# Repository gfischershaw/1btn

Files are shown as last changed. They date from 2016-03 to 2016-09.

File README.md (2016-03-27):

# [1btn](http://www.1btn.space)

1btn (one button) uses the internet to complete a task with the simple, satisfying click of a single button. It connects to the internet over Wi-Fi to trigger whatever action you have assigned to it using a simple, online interface. One click, one task. It’s that simple.

Unlike many other “Internet of Things” devices, 1btn does not maintain a continuous connection to the internet. Instead, it sleeps until it is pressed, then it connects to the internet, performs the assigned task, tells you the outcome via its multi-colored LEDs, and then returns to rest.

As the Internet of Things has expanded, we’ve noticed an unfortunate trend: the increasing use of smartphones to control IoT applications. We don’t think a smartphone provides the best or simplest UI for this purpose. Think of all the steps you need to take to send a single instruction with a smartphone: find the phone, wake it up or power it up, enter your passcode, keep swiping until you find and start up your smart app, select the appropriate control, activate it, and then put the phone back to sleep.

We think there’s a better way, a tried-and-true, more intuitive way, to activate a single task or function, and that’s with a button. Why are buttons such a great idea? A button is the simplest user interface for a single-repetitive-programmable task. They are simple exactly because they are designed for a single-task. More importantly, buttons are easy-to-understand, they are familiar, intuitive, and provide immediate, satisfying physical feedback when pushed.

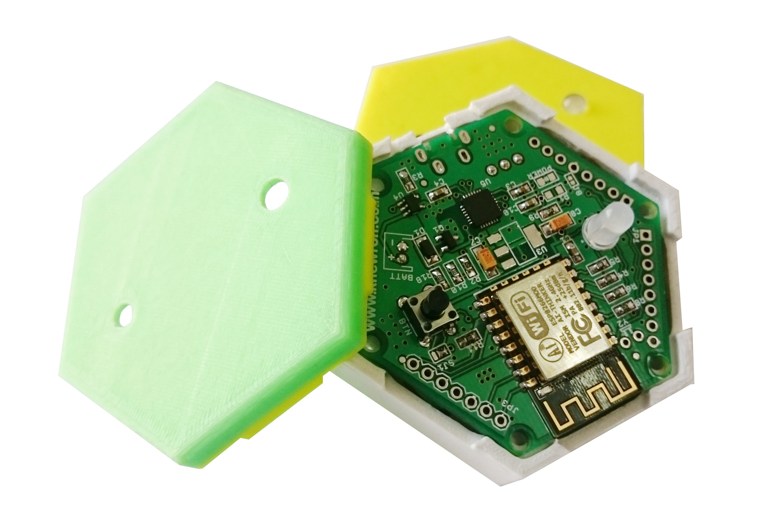
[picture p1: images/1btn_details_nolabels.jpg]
inside view of 1btn


**Specifications**
- Size: about 60mm diameter
- Casing: hexagonal 3D printed using PLA material
- Built-in rechargeable battery: 3.7V 500mAH
- Built-in wifi module: ESP8266 - ESP-12F
- Weight: approx. 50 grams
- Color: white case bottom with multiple color options for the top (red, pink, blue, yellow, white, and green)

## License
See the [LICENSE] (https://github.com/anandtamboli/1btn/blob/master/LICENSE) file

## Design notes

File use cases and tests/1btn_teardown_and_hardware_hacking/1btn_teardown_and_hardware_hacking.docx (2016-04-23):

1btn teardown and hardware hacking

1btn is not just open source product but it is an open hardware design too. This means, proud owners of 1btn do have access to firmware, hardware design files as well as actual hardware.

While you already have an overview of technical specifications for 1btn, today I will show you what exactly has been packed inside the 1btn casing. A detailed tear down with explanation will tell you more than what meets an eye about 1btn.

If you have unsealed 1btn, then it is easy to pry open the casings with the help of finger-nail or a blade or a flat-head screw driver. However, if you’ve got a sealed version, be extremely careful while doing this as there are higher chances of damaging top and bottom casings while prying them open.

A high level view

1btn is comprised of 4 main parts: top casing, bottom casing, PCB assembly and a LiPo battery.

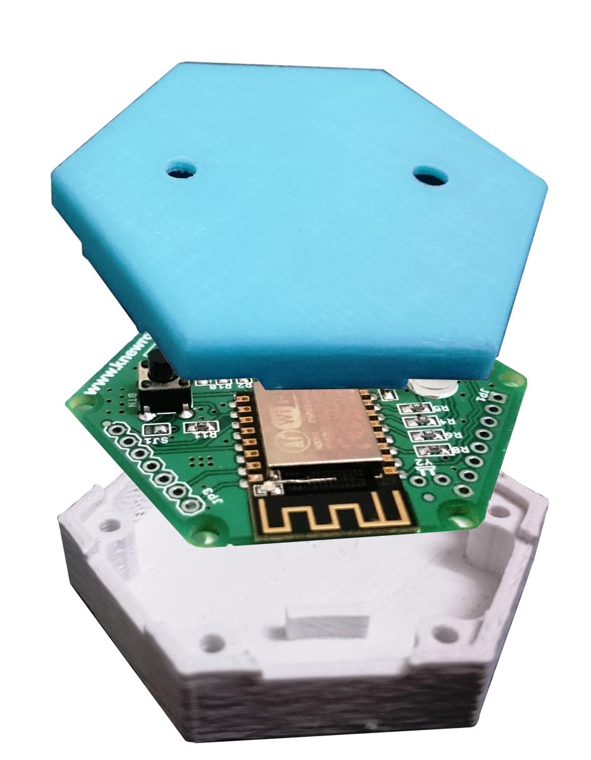
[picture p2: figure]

Exploded view in figure 1 shows these 4 parts. Did you notice two small ribs in the middle of bottom casing? They are meant for fitting the battery snugly between them. Unfortunately, LiPo batteries do not come in uniform size despite being same capacity and therefore there are two designs of bottom casing. One is with these ribs and one is without – to accommodate slightly wider batteries.

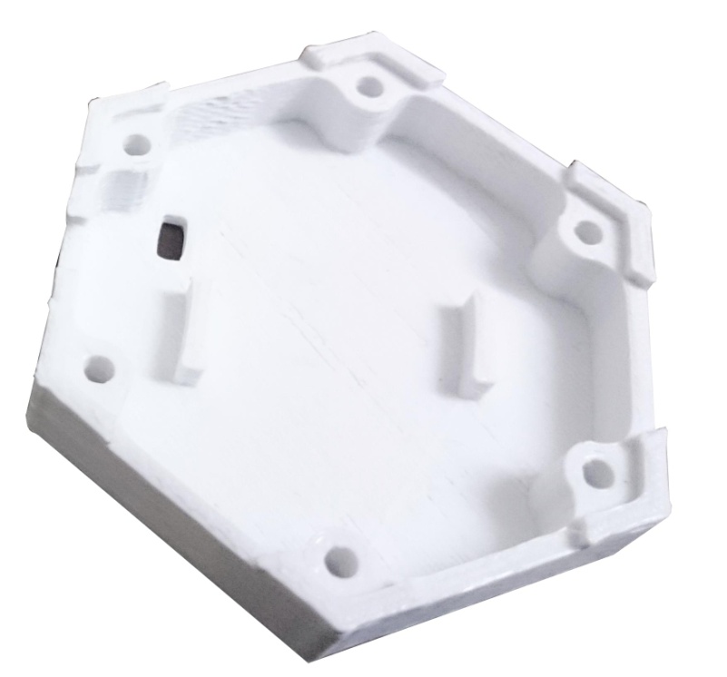
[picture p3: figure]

1btn PCB assembly rests on six mounting holes molded into bottom casing which maintain enough distance between the battery and PCB assembly. Interestingly, if you don’t want to seal your 1btn permanently but want to make the fitting firm, you could use 3mm screws (insert from bottom side of casing) to tightly join both the casings and PCBA sandwiched in between, see figure 2. Isn’t that a neat arrangement?

More about PCB assembly

1btn PCB is a double sided board with components placed on both sides, majorly on top side though. You will see that in figure 3 there is 3.3V regulator IC placed just under ESP module, which is not seen in some of the other shots of 1btn. That is because the board has been designed to accommodate two different voltage regulators in order to make design manufacturing and inventory friendly. This gives the manufacturing flexibility to use whichever part is available and populate the board accordingly.

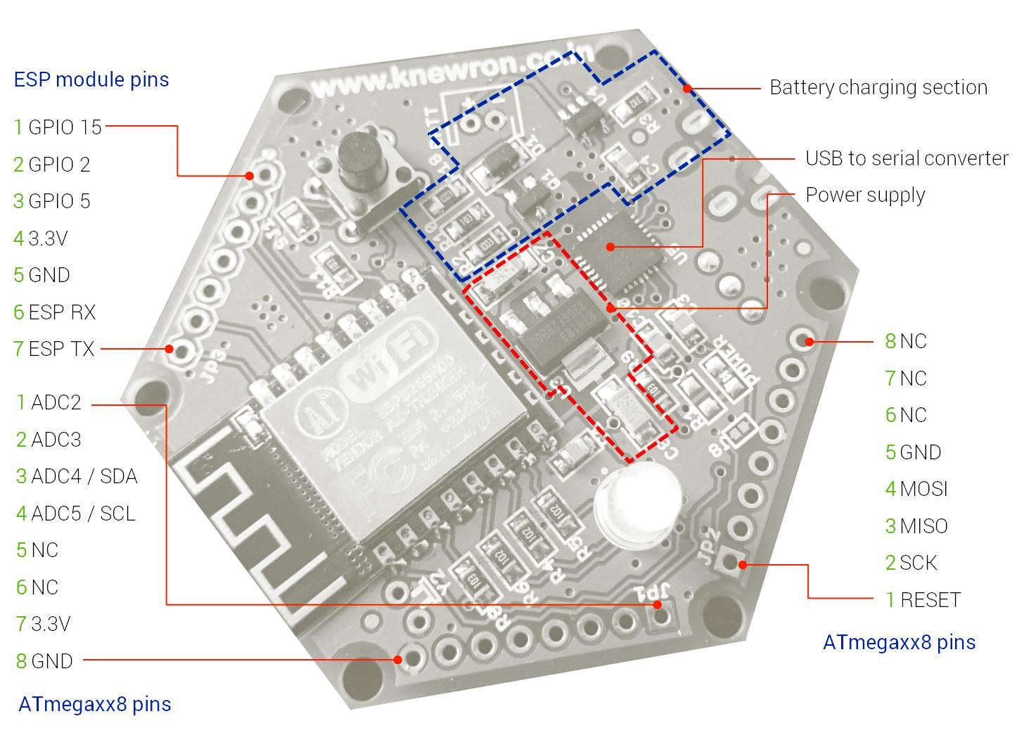
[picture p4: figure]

You would also see that there are three expansion ports, JP1, JP2 and JP3 on the board which essentially extend a few more pins of ESP, ISP pins of ATmegaxx8 controller (yes, there is place for one) and analog pins of the same. That means, with enough space inside the casing of 1btn and a few extra I/O taken out, you can add more sensors and enhance 1btn functionality.

Figure 4 shows bottom side of the PCBA where you will see 4 major sections, one being USB port, second being on-off switch of 1btn, third is jumpers’ section and fourth is footprint for ATmegaxx8P part. You can use any variant from ATmega328P, ATmega88/V or ATmega168/V and alike.

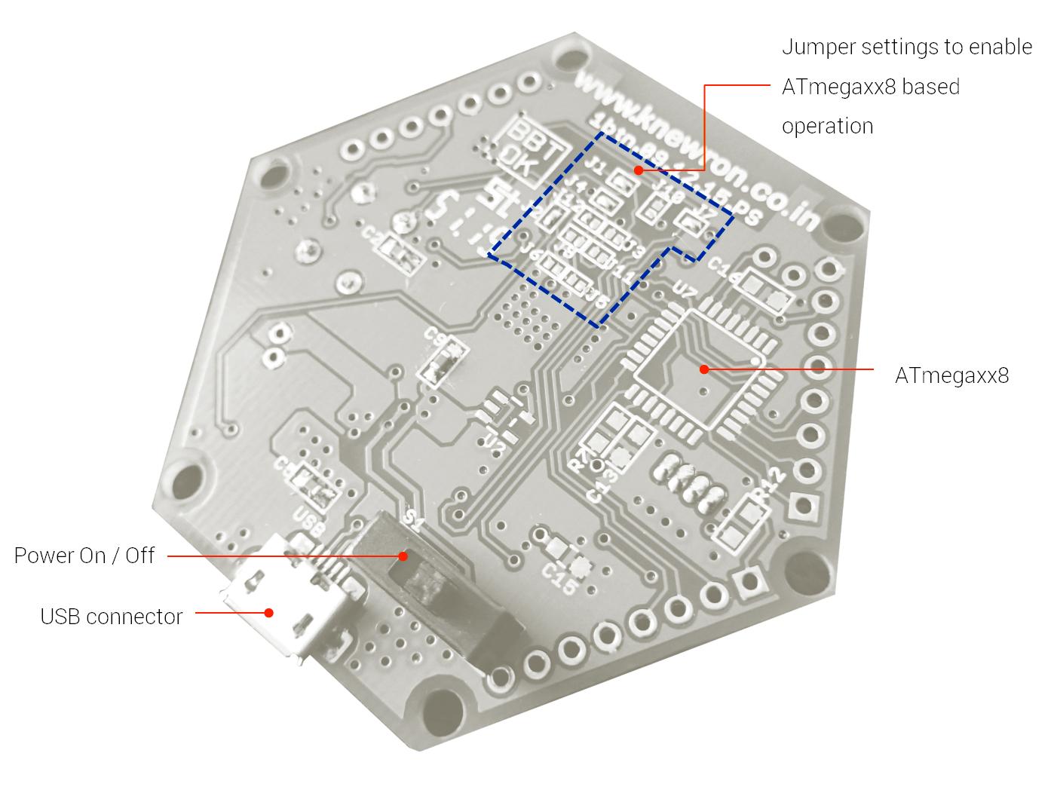
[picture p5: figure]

In order to enable ATmega based operation, a few jumper settings need to be changed (more on that would be available in BOM on github) and then you will have power of ATmega along with ESP power, a great combination! A button press then can be diverted from ESP to interrupt pin of ATmega and with RTC crystal placed on board (it’s there too) you can have super low power IoT device which sleep walks most of the time.

Why you would do that, one may ask. With addition of ATmega here, you could basically convert 1btn into multi-press device for starters. Plus you can do a lot with addition of sensors, and wifi together – say your next IoT project in nice little hexagonal casing?

Basically, if you hack 1btn this way, it can change 1btn functionality completely into something else, novel, nifty and interesting.

About the battery charger of 1btn

One of the interesting things 1btn’s battery charging circuit is that you don’t have to turn the button ON to charge the battery. The on-off switch is placed after the battery charger and before regulator circuit which enables you to put it to charge while switch may be still in OFF position.

1btn is open source hardware

All the components are chosen in such a way that they are easily available at lower MOQ or single piece quantities, everywhere. Most of the passives are in 0805 / 0603 packages which are easy to hand-solder. And there is absolutely nothing complicated on the board which would discourage a maker / hacker from playing around.

Designing for manufacturing as well inventory and part substitutions is very important when working on an open source design. It is to make sure that if part A is not available then part B (or part C) can be used instead without hampering functional or safety aspects.

I strongly believe that while making open source hardware, it is important to keep makers in perspective and design the product accordingly. Using unnecessary sophisticated parts and miniature components works against the spirit of play that encourages community to improvise, enhance, and experiment.

All the design files of 1btn are currently being developed and would be made available on github very soon.

In the end…

A few weeks ago geek.com had this to say about 1btn (http://www.geek.com/news/1btn-is-a-powerful-open-source-do-it-all-button-for-the-internet-1651036/) – “1btn is a powerful, open source, do-it-all button for the Internet; it can already do a lot, and once there’s a community hacking away at it, the possibilities are virtually limitless.”

Happy hacking with 1btn!

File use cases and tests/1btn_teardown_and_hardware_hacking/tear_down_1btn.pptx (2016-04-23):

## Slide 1

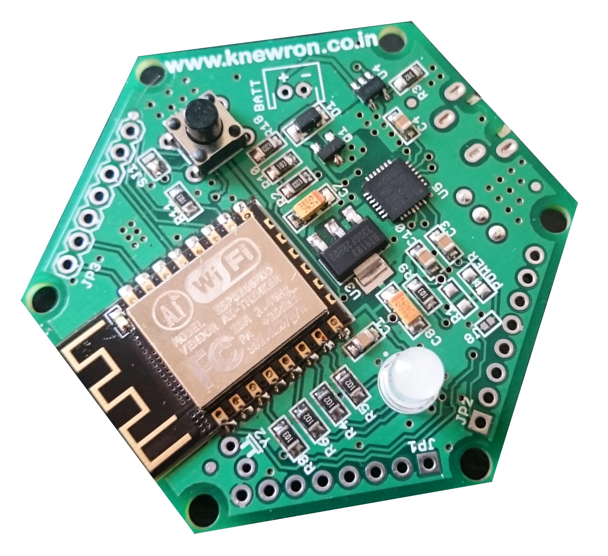
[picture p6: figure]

ESP module pins

1 GPIO 15
2 GPIO 2
3 GPIO 5
4 3.3V
5 GND
6 ESP RX
7 ESP TX

1 ADC2
2 ADC3
3 ADC4 / SDA
4 ADC5 / SCL
5 NC
6 NC
7 3.3V
8 GND

ATmegaxx8 pins

Battery charging section

USB to serial converter
Power supply

8 NC
7 NC
6 NC
5 GND
4 MOSI
3 MISO
2 SCK
1 RESET

ATmegaxx8 pins

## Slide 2

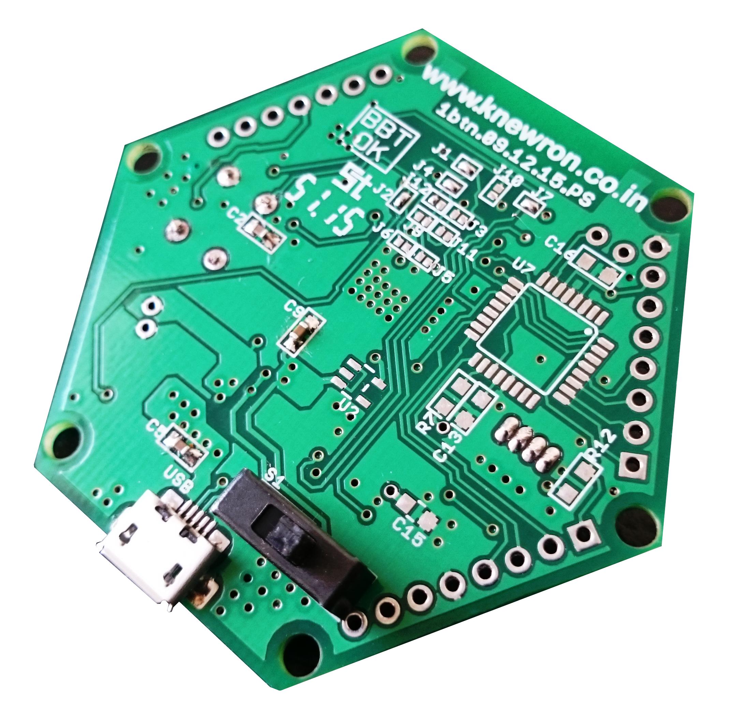
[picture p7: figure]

Jumper settings to enable ATmegaxx8 based operation

ATmegaxx8

Power On / Off

USB connector

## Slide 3

Pin # 1
Pin # 7

Pin # 1
Pin # 8

JP 3 - ESP module pins

Section 1

Section 2
Section 3

Pin # 8
Pin # 1

JP2 - ATmegaxx8 pins

JP1 - ATmegaxx8 pins

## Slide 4

Section 4

Section 5

Power On / Off

USB connector

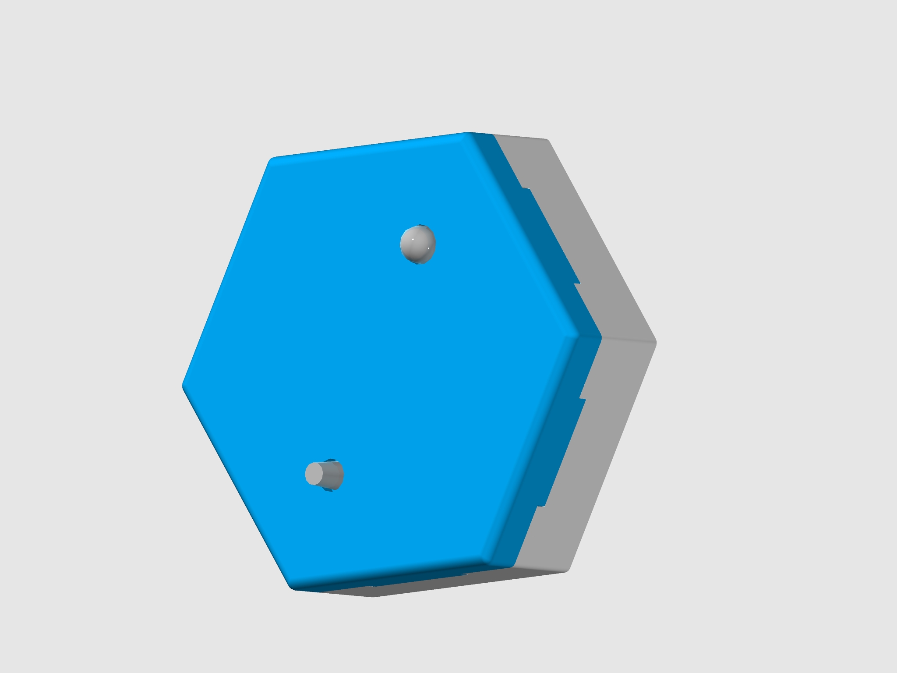
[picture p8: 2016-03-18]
mechanical/render v1/blue_white.jpeg

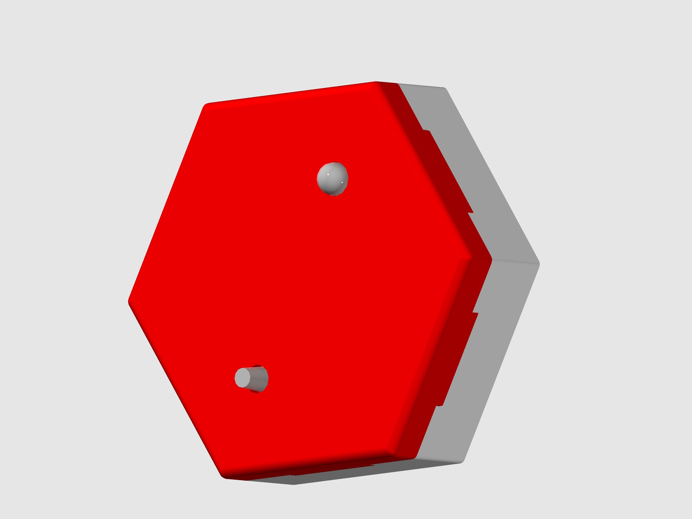
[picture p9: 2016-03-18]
mechanical/render v1/red_white.jpeg

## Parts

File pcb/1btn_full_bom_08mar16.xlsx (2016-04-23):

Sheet: BOM
Sr. | Level | Section | Reference Designator | Qty | Category | Part Description | Part Value | Part Package | Remarks | MPN
1 | --1 | Enclosure | . | 1 | Enclosure | 3D Printed Top Casing | Hexagonal PLA / ABS (Various Colors) | . | RED, GREEN, BLUE, YELLOW, WHITE, PINK | .
2 | --1 | Enclosure | . | 1 | Enclosure | 3D Printed Bottom Casing | Hexagonal PLA / ABS (White) | . | ONLY WHITE | .
3 | --1 | Enclosure | On bottom casing | 1 | Label | MAC ID Label | 25.4mm x 5mm | . | Sticker with MAC ID of WIFI module | .
4 | --1 | Enclosure | Packed separately | 1 | Sticker | Velcro round sticker | 25.4mm Diameter | . | . | .
5 | -- --2 | Battery | BATT | 1 | Battery | Lithium Polymer Battery | 3.7V 500mAh (50mm x 30mm) | . | . | .
6 | -- --2 | PCB | . | 1 | Bare PCB | Printed Circuit Board | Hexagonal Custom PCB | . | . | .
7 | -- -- -- 3 | Battery | U4 | 1 | IC | Battery charge controller SMD | MCP73831T-2ACI/OT | SOT 23-5 | MICROCHIP | MCP73831T-2ACI/OT
8 | -- -- -- 3 | Battery | Q1 | 1 | MOSFET | MOSFET P channel | BSH205G2R | SOT 23-3 | NXP | BSH205G2R
9 | -- -- -- 3 | Battery | R5, R2 | 2 | Resistor | Resistor SMD 0603 | 100K +/- 5% | SMD 0603 | VISHAY | CRCW0603100KJNEA
10 | -- -- -- 3 | Battery | R4 | 1 | Resistor | Resistor SMD 0603 | 470K +/- 5% | SMD 0603 | VISHAY | CRCW0603470KJNEA
11 | -- -- -- 3 | Battery | R3 | 1 | Resistor | Resistor SMD 0603 | 2K +/- 5% | SMD 0603 | VISHAY | CRCW06032K20JNEA
12 | -- -- -- 3 | ESP | C5, C6 | 2 | Capacitor | Capacitor SMD 0603 | 0.1uF +/- 10% 25V | SMD 0603 | MULTICOMP | MC0603B104K500CT
13 | -- -- -- 3 | ESP | ESP | 1 | WiFi Module | ESP12 Module | ESP12F | ESP 12F | AI THINKER | ESP12F
14 | -- -- -- 3 | ESP | R6, R7, R8 | 3 | Resistor | Resistor SMD 0603 | 10K +/- 5% | SMD 0603 | VISHAY | CRCW060310K0JNEB
15 | -- -- -- 3 | ESP | BTN | 1 | Button | Tact Switch Push to ON | 4 pin PTH 7mm Height | TACTILE PTH | . | Not available
16 | -- -- -- 3 | ESP | J1, J2, J4, J7 | 4 | Jumper | Short | . | SMD solder | . | .
17 | -- -- -- 3 | ESP | SJ1 | 1 | Jumper | Short to RST | . | SMD solder | . | .
18 | -- -- -- 3 | Power | C1, C4 | 2 | Capacitor | Capacitor Pol SMD 3528-KIT | 47uF +/- 10% 16V | SMD 3528 (1206) | KEMET | T491B476K010AT
19 | -- -- -- 3 | Power | C2, C3 | 2 | Capacitor | Capacitor SMD 0603 | 0.1uF +/- 10% 25V | SMD 0603 | YAGEO or equivalent | MC0603B104K500CT
20 | -- -- -- 3 | Power | U3 | 1 | IC | Voltage Regulator SOT223 | RT9183-33GGF | SOT 223 | RICHTEK | RT9183-33GGF
21 | -- -- -- 3 | Power | D1 | 1 | Diode | Shottky Diode | PMEG3015EH | SOD 123 | NXP | PMEG3015EH
22 | -- -- -- 3 | Power | S1 | 1 | Switch | SPDT Switch - 12E17 | SPDT | PTH 12E17 | . | Not available
23 | -- -- -- 3 | MCU | J3, J5, J6, J8, J9, J10, J11, J12 | 8 | Jumper | Open | . | SMD solder | . | .
24 | -- -- -- 3 | RGB | R9, R10, R11 | 3 | Resistor | Resistor SMD 0603 | 2K +/- 5% | SMD 0603 | VISHAY | CRCW06031K50JNEA
25 | -- -- -- 3 | RGB | D2 | 1 | LED | RGB LED CC PTH 5mm | RGB LED CC PTH 5mm | LED RGB CC | . | Not available
26 | -- -- -- 3 | RGB | CA | 1 | Jumper | Open (if D2 is CC type, short if CA type) | . | SMD solder | . | .
27 | -- -- -- 3 | RGB | CC | 1 | Jumper | Short (if D2 is CC type, open if CA type) | . | SMD solder | . | .
28 | -- -- -- 3 | USB | C7, C8, C9 | 3 | Capacitor | Capacitor SMD 0603 | 0.1uF +/- 10% 25V | SMD 0603 | YAGEO or equivalent | MC0603B104K500CT
29 | -- -- -- 3 | USB | U5 | 1 | IC | CP2102 SMD MLP28 | CP2102_USB_UART | SMD MLP28 | SILICON Labs | CP2102
30 | -- -- -- 3 | USB | USB | 1 | Connector | USB MICROB | USB-MICROB | USB MICROB SMD | . | Not available
31 | -- -- -- -- 4 | ESP | . | 1 | Firmware | Custom Firmware for ESP12F | NodeMCU 9.60 + Additional LUA files | . | 1btn Program files | .

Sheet: jumper settings
Jumper | ESP12 - 1 | ESP12 - X | ATmega328p
J1 | Short | Short | x
J2 | Short | Short | x
J3 | x | x | Short
J4 | Short | Short | x
J5 | x | x | Short
J6 | x | x | Short
J7 | Short | Short | Open
J8 | x | x | Short
J9 | Open | Open | Open
J10 | Open | Open | Short
J11 | Open | Open | Open
J12 | Open | Open | Short
SJ1 | Short to RST | Short to I/O 0 | Open
Add-on components
R12 | . | . | 10K
R7 | . | . | 0E
C16 | . | . | 1uF
C15 | . | . | 0.1uF
C13 | . | . | 0.1uF
U7 | . | . | mega328p
JP2 | . | . | 5 Pin berg (ISP)
Y2 | . | . | 32.768 KHz

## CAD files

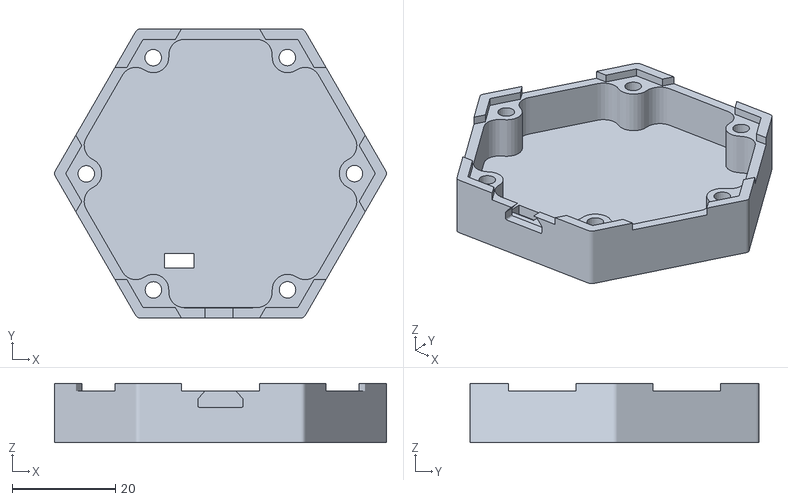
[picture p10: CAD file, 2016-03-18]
mechanical/prototype v0.4/bottomcase5.1_07032016.stl
64.3 x 56.0 x 11.5

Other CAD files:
mechanical/prototype v0.4/top coverv5.1_07032016.dwg
mechanical/release v1/top coverv5.1_07032016.dwg

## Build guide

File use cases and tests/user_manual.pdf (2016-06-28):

# 1btn – Open Source WiFi Connected Button

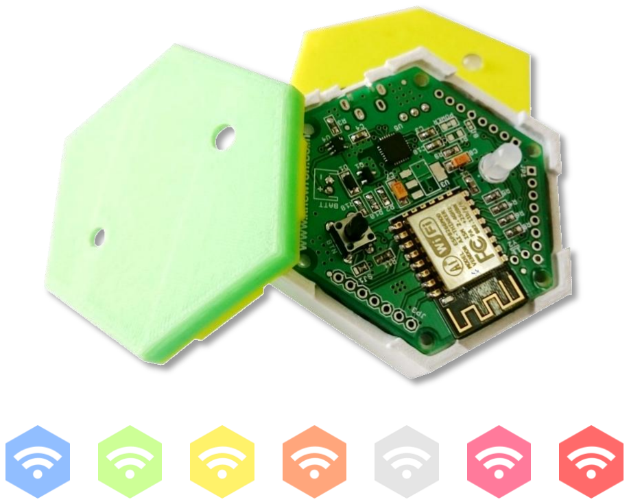
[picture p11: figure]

1btn (one button) uses internet to complete the task with simple, satisfying click of a single button. It connects to the internet over WiFi and triggers whatever action you have assigned to it using a easy online interface. One click, one task.

# 1btn specifications

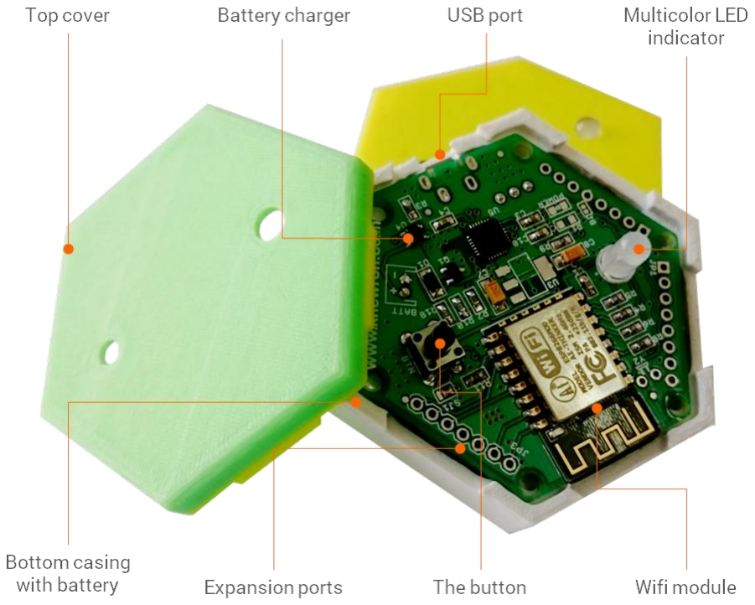
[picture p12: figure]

- Product Name | ONE BUTTON
- Part Number | 1BTN0915V1
- Connectivity | USB, WIFI
- WiFi Type | 802.11 b/g/n

## - Enclosure Type 3D Printed with PLA

- Net Weight | 50 grams
- Dimensions | 6cm x 6cm x 1.5cm
- Battery | 4.7V, 500mAH, LiPo
- Input Power | 5VDC, 500mA
- Color Options | Blue, Green, Yellow,
| White, Red, Pink, Amber

# pairing with your wifi

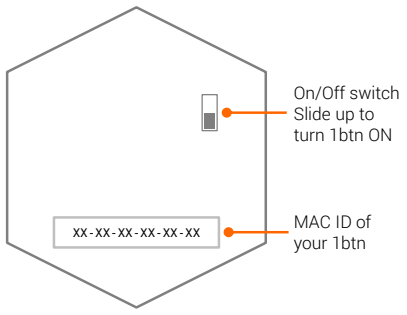
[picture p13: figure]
On/Off switch Slide up to turn 1btn ON; MAC ID of your 1btn

- When you turn 1btn ON, it’s main action starts.
- 1btn starts searching for known wifi hotspot or access point.
- If nothing found, it enters into AP mode.
- While in AP mode you can access it’s config page to provide credentials

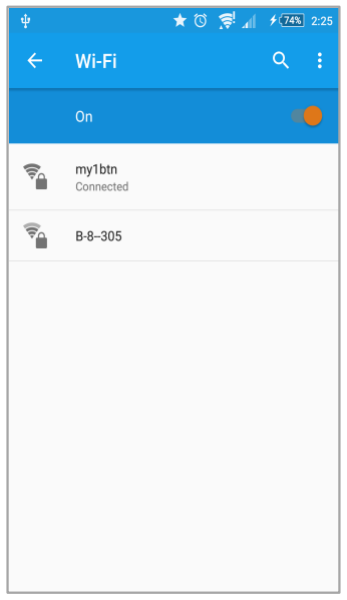
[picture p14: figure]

- Search for access point “my1btn” in your smart phone’s / computer’s wifi list.
- Connect to this access point using password as “12345678”.

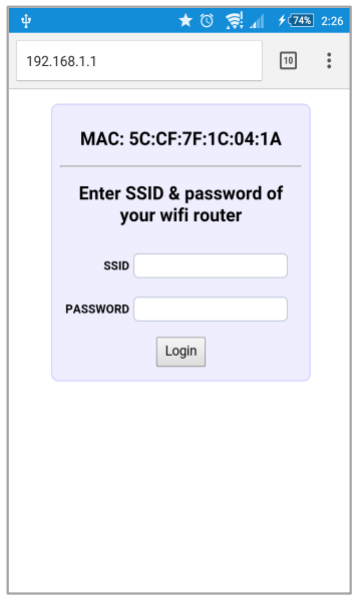
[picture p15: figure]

- Open the browser and access the page with IP 192.168.1.1
- Provide your wifi credentials and press Login.
- If 1btn successfully connects to given wifi, it will restart and send it’s first ping. If for any reason it cannot connect to the wifi, it will just come back to the same config page again.

REMEMBER
1btn typically remembers credentials even when in off condition. However, every time you turn on 1btn, your wifi / hotspot must be reachable. If not found, 1btn will clear those credentials and enter into AP mode for new ones.

TIP
If you want to reset or erase existing credentials or want to provide new ones; power cycle 1btn while it is kept out of range of paired wifi. When restarted, 1btn will check for previous wifi and won’t find it, and it would then enter into AP mode again.
- When restarted successfully, 1btn will send an event to 1btn servers and the configured action should take place – you will see GREEN blink in case of success.
- If 1btn is not yet configured using webservice or the event was unsuccessful, you will see RED blink.
- Thereafter 1btn will enter into deep-sleep mode and will be ready for button press to do the configured job.

# button-action configuration

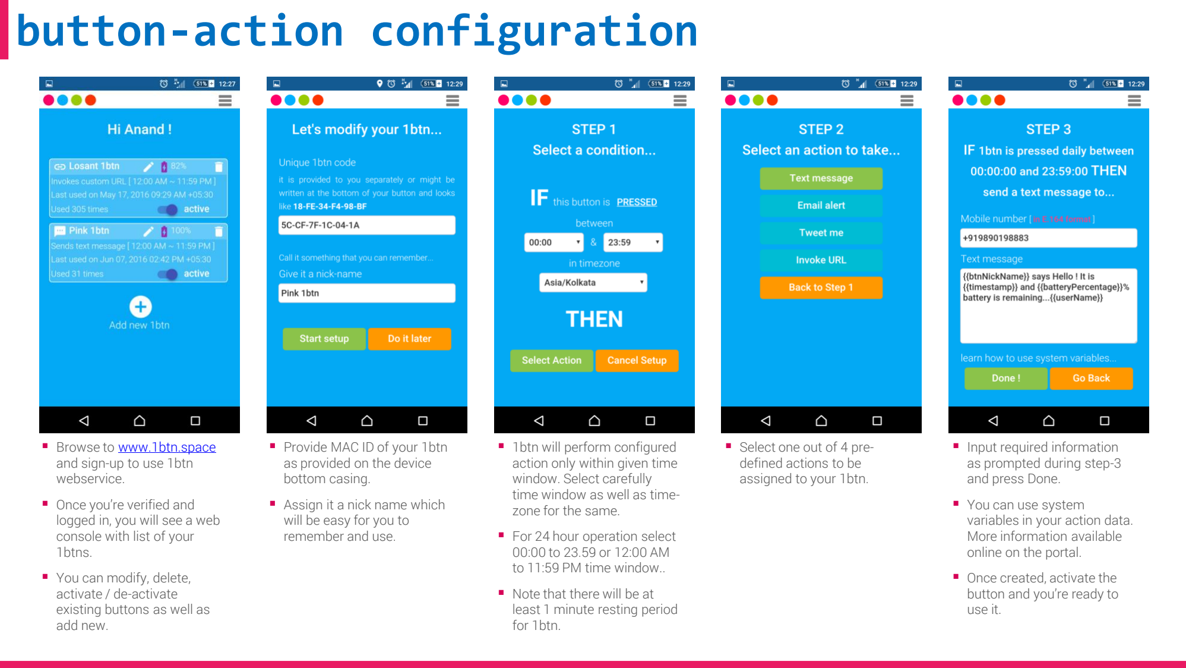
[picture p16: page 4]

- Browse to www.1btn.space and sign-up to use 1btn
webservice.
- Once you’re verified and logged in, you will see a web console with list of your
1btns.
- You can modify, delete,
activate / de-activate
existing buttons as well as add new.
- Provide MAC ID of your 1btn as provided on the device
bottom casing.
- Assign it a nick name which will be easy for you to
remember and use.
- 1btn will perform configured action only within given time window. Select carefully
time window as well as timezone for the same.
- For 24 hour operation select 00:00 to 23.59 or 12:00 AM to 11:59 PM time window..
- Note that there will be at least 1 minute resting period for 1btn.
- Select one out of 4 predefined actions to be
assigned to your 1btn.
- Input required information as prompted during step-3
and press Done.
- You can use system
variables in your action data. More information available online on the portal.
- Once created, activate the button and you’re ready to use it.

# how does 1btn work ?

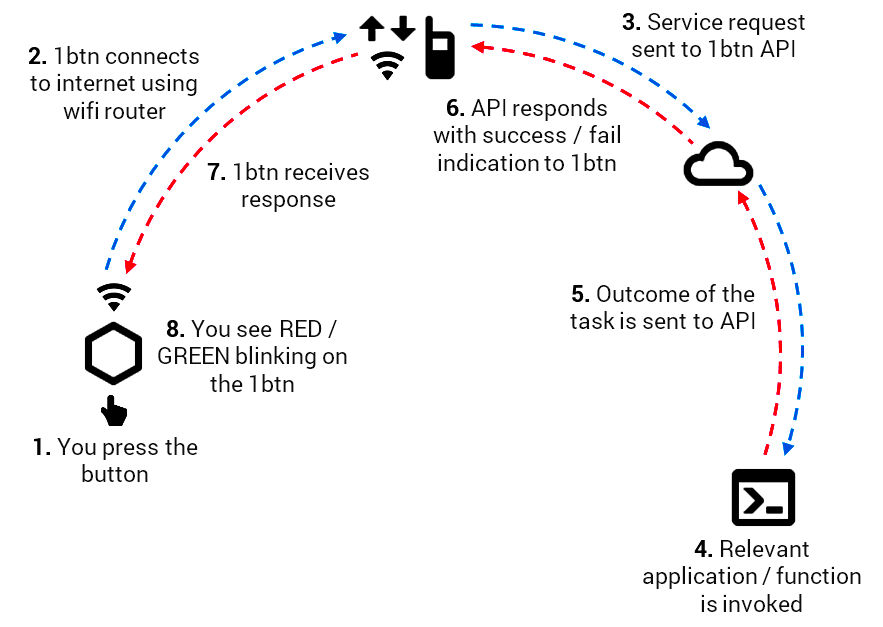
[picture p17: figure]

1. If powered ON, 1btn will remain in deep-sleep all the time.

## 2. When you press the button on 1btn device, it triggers the

micro-controller inside and wakes it from deep-sleep.

## 3. 1btn then tries to connect to the wifi router using credentials

you have already provided during configuration.

## 4. If the wifi connection fails, it enters back to AP mode and

would start blinking BLUE.

## 5. Upon successful connection to wifi, 1btn sends service

request to 1btn API servers.

## 6. Depending upon the configuration you have setup online for it, action is performed and server responds with success /

failure response.

## 7. If the action was successful, you will see GREEN blinking or

else RED blinking on the device.

8. 1btn goes back to deep-sleep again.

# taking care of your 1btn

CHARGING A rechargeable 500mAH lithium polymer battery is part of 1btn. Typical full charge should take you upto about 300 button presses. And you can recharge the battery by plugging in it with a mobile phone charger (or laptop USB port) with micro-USB cable. A power source of 500mA capacity can take about an hour to fully charge the battery

## POWER CYCLE

Once you power up 1btn, there is no need to turn it off.

## 1btn usually remains in deep-sleep mode and consumes negligible amount of current. However, if you plan not to use it for longer period of time, it is

good idea to turn if off.

## FIXING AND PLACEMENT 1btn is good to be used as a table top device which can be moved around when needed. However, if you choose to fix it at one place, double sided tape could be an option. Remember to make an arrangement in such a way that you can take 1btn out when it’s due for re-

charging.

# 1btn

OPEN SOURCE WIFI CONNECTED BUTTON

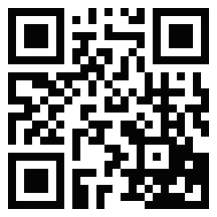
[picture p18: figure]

1 B T N 0 9 1 5 V 1 | www.1btn.space

## T E C H N O L O G I E S

### designed & developed by

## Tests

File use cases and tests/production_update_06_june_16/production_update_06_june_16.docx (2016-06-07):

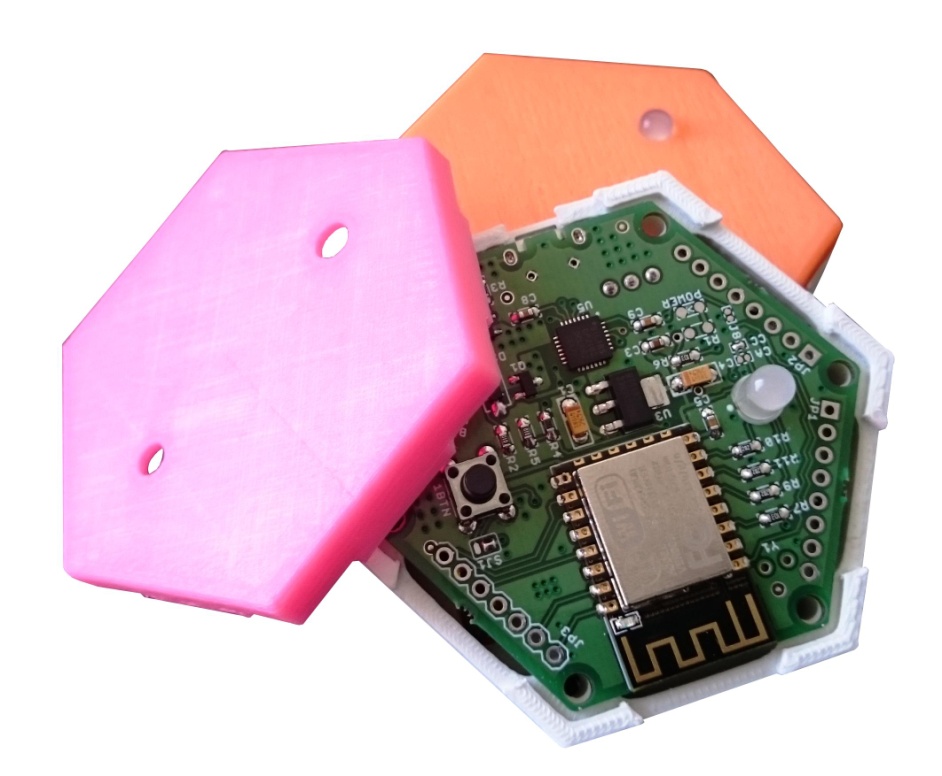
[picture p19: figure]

1btn in making…

First of all thanks to all the backers for sincere support to the project and making large batch production of 1btn feasible.

While we kept campaign goal to be $1 to make 1btn, no matter what, we were secretly hoping for orders of at least 100 units. And we are happy to tell you that we stand at about 122 orders till date; and they still counting.

MANUFACTURING PLAN AND CURRENT STATUS

Most of the things were set in motion while we were in last sprint of the campaign. This helped us in starting things earlier than planned.

As of today component sourcing is 100 % complete. 3D printing of enclosures is in progress; and it’s about 80% complete while we release this update. 1btn enclosures are getting 3D printed at our manufacturing partner’s workshop in Pune, India.

PCB assembly and programming is in progress too and about 40% of the work is done. PCBA is also being done in Pune, India.

Since most of the parts are locally sourced and manufactured, we have now full control over the entire process and so the timeline and costs.

While we already have created framework for web-service for 1btn usage, API creations and webservice modifications in progress for development partners to take up further application development on. Last few minor changes are being done before we release it to our development partners for experimentation.

In a nutshell, so far everything is on track and we are in control of the timeline.

WHAT WILL HAPPEN THIS MONTH?

We are positive that later this month we will be dispatching units for development partner backers. By end of the month some more upgrades in webservice would be done.

We will also update github repo with minor changes in designs that we did during manufacturing of 1btn PCBA.

All backers would be contacted for address verification later this month. This is to ensure that your 1btn can reach to you in time when dispatched.

UNTIL YOU RECEIVE YOUR PLEDGES…

We are making a few extra 1btn units to fulfill pre-orders as well as orders after that; so please get the word out and let everyone know if they still wish to grab one.

In the meantime, feel free to write to us and make suggestions; lend us a helping hand, if you can, in writing more and more use cases of 1btn.

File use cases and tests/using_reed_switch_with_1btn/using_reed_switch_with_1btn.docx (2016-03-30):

Hack # 1: Reed switch activated 1btn

Unlike many other “Internet of Things” devices, 1btn does not maintain a continuous connection to the internet. Instead, it sleeps until pressed, and then it connects to the internet, performs the assigned task, tells you the outcome via its multi-colored LED, and returns to rest.

But what if you don’t even want to press that single button? What if you want 1btn to respond to an event by performing its task? This update will explain how to modify your 1btn to do just that.

What’s the use case for this modification?

Let’s say your pet platypus is very sensitive to the cold and you’re about to leave him in the care of a house-sitter for a week. You’ve told the house-sitter to never open the window in the room where the platypus lives. To ensure your wishes are complied with, you’d like to be warned whenever that window is opened.

To do this, we will first modify the 1btn hardware to trigger the device upon an event (window opening) and then we’ll configure the software to send an email alert. You’ll see that it’s easy to modify 1btn’s hardware for all sorts of purposes.

What’s needed for this modification?

You’ll need a 1btn, obviously, and some sort of sensor. In this case, we’re going to use a basic reed switch. (A reed switch operates when it encounters a magnet.) We will be using a normally open (NO) type reed switch, which is similar to the tactile-switch on the 1btn. This way we can connect the reed switch in parallel with the tactile switch, so we don’t need to remove the existing switch and its functionality. Along with the reed switch, you’ll also need a small magnet and some basic electronic supplies (soldering iron, solder, wire, etc.)

Step 1: open 1btn and attach reed switch

Carefully pry open your 1btn and then remove the PCB and turn it over. Solder the two wires connected to your reed switch onto the pads of the built-in button as shown in Figure 1. This will connect the reed switch in parallel with the 1btn’s button.

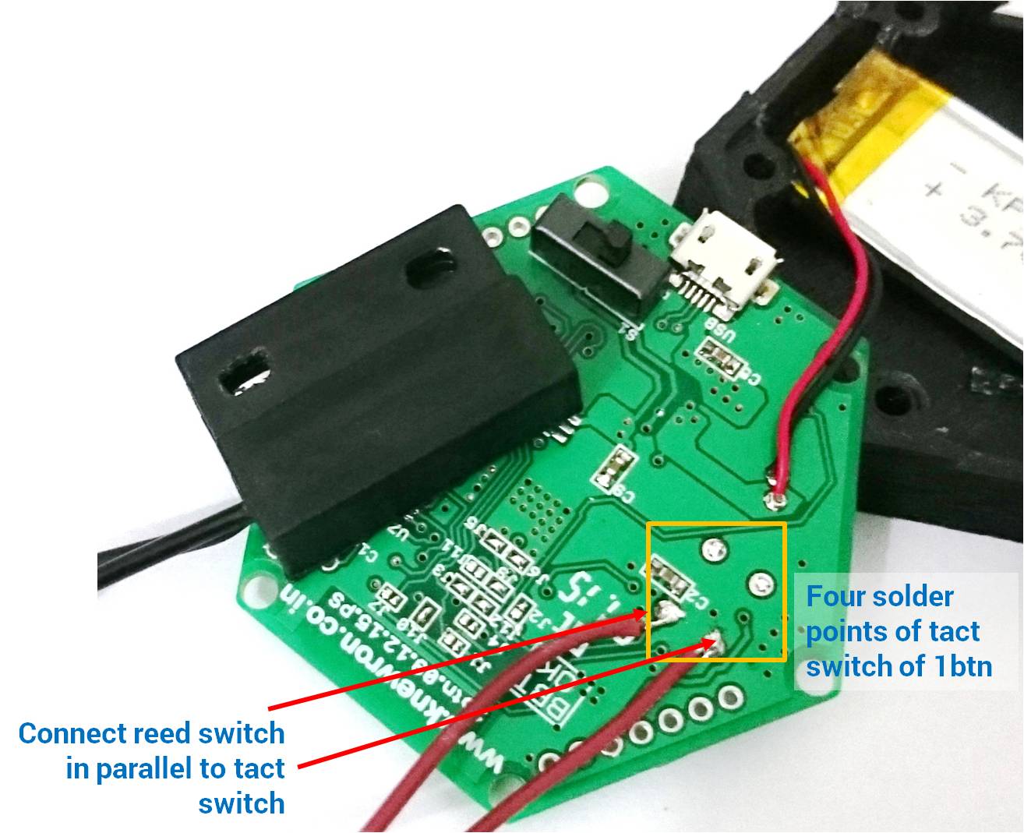
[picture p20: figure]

Step 2: reassemble 1btn

Now we need to route the reed switch’s wires to the outside of the 1btn case. We can use the USB connector’s opening for this purpose, as shown in Figure 2.

Thread the wires through the opening, re-position the PCB back onto its supports, and close the lid tightly. See Figure 3.

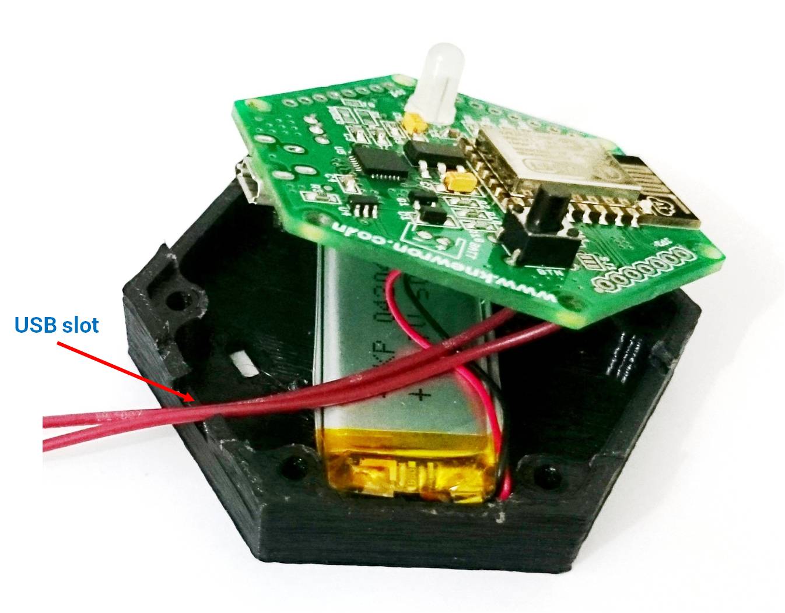
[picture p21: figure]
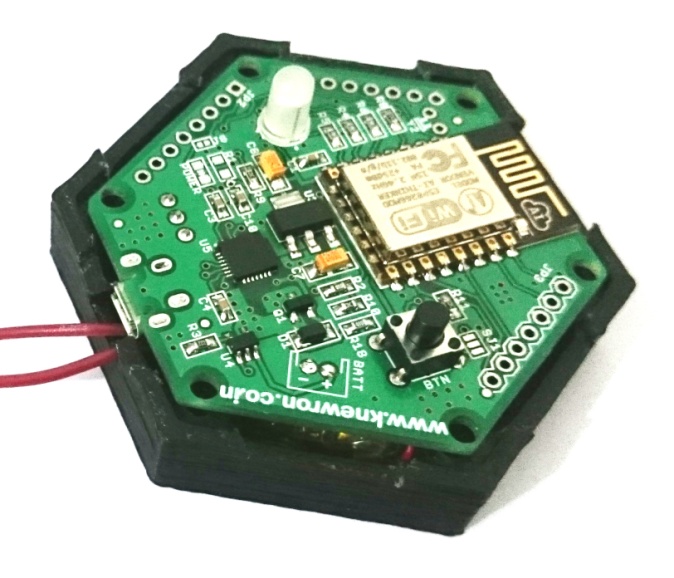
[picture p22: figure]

The end result should look something like this…

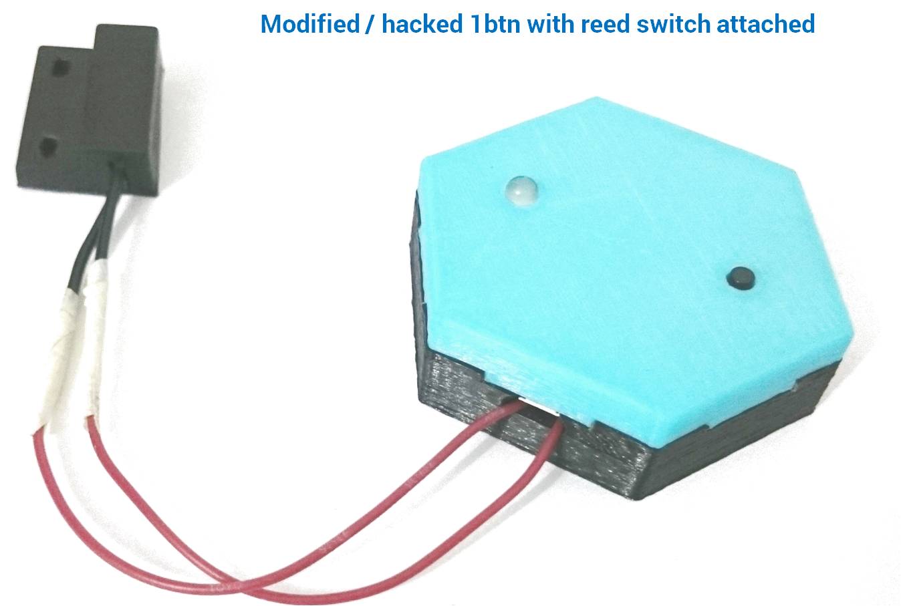
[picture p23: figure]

Step 3: install modified 1btn

At this point, our modified 1btn is ready for installation. You can use double-sided tape to attach the 1btn and reed switch to the window frame, as shown in Figure 5. The magnet then gets fixed to the window casement.

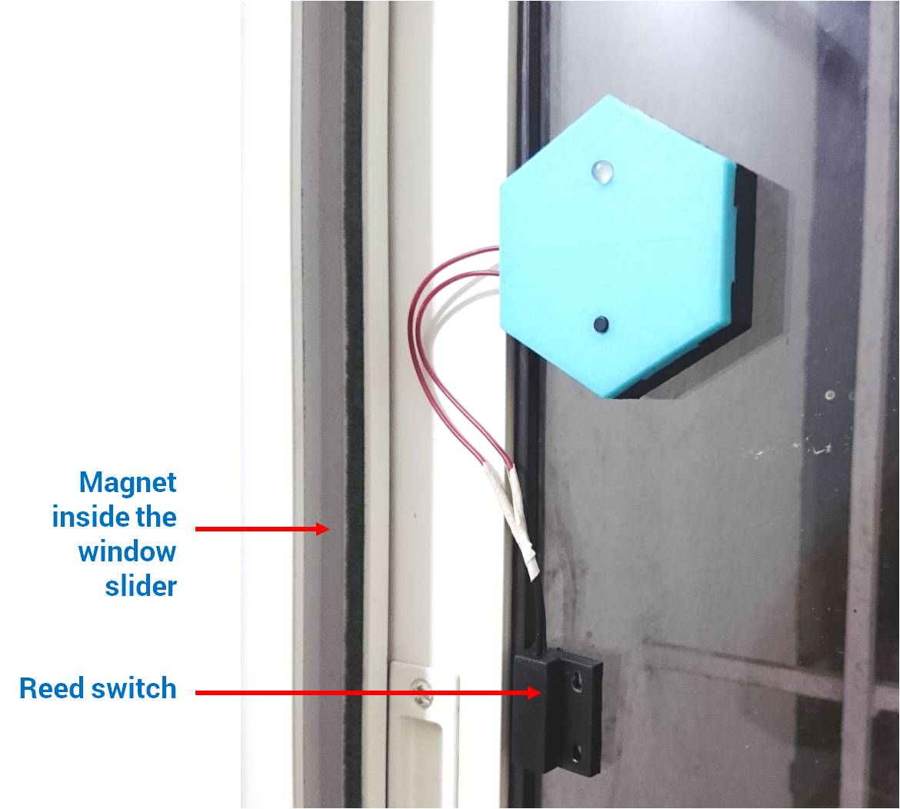
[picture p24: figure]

Step 4: configure the button action on web-console

In order to get an email alert when the window opens and activates the reed switch, you’ll need to configure the 1btn using the web-console. Set up the button, either by adding it as new or modifying its existing settings, as shown in screenshot 1. Note how the 1btn gets a meaningful nickname so you can better identify it. If you plan to have multiple such sensors, you may wish to give them each unique names to help keep them straight (window#1, window#2, etc.).

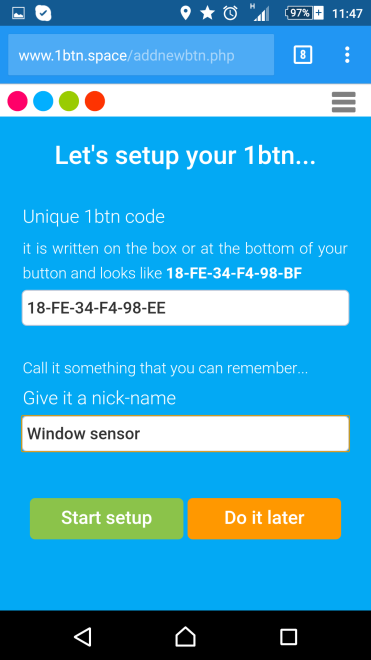
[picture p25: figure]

Next we setup the time of the day during which we want the 1btn to be active.

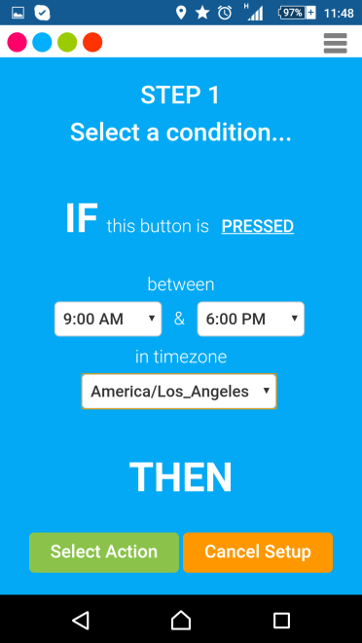
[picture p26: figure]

And then we set the “action to take” as an “Email alert” as shown in Screenshot 3:

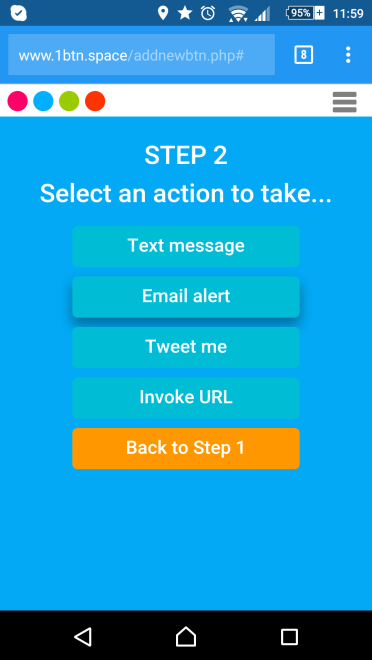
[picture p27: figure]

Next, we provide an “Email ID” (address) where the email alert will be sent, as shown in Screenshot 4 below. Notice the closing signature in the Email message – {{btnNickName}}. This is a system variable which will get replaced with the nickname we provided during configuration. (i.e. Window Sensor) when the email is sent.

Note: there are many other system variables you can use in your message. Check out the list on the 1btn web-portal.

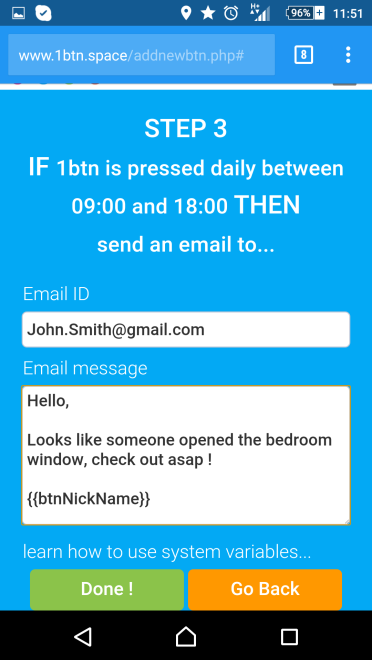
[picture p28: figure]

Set up and configuration is now complete. Click the “Do it now!” button to activate your 1btn.


Step 5: test and put it to use

Finally, test your setup and configuration by triggering the action (opening the window) and verifying that you receive the alert email. That’s it! Your modified 1btn is now operational and ready to help you in your daily life.

Happy button hacking!

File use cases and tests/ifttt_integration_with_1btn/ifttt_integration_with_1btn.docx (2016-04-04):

IFTTT integration with 1btn

One of the useful scenarios while using 1btn is integrating it with existing web-services. Services such as IFTTT, Zapier, and others are quiet useful for this purpose.

1btn comes with four pre-defined actions viz. sending text message (SMS), sending email, twitter post and invoking a URL (custom script, API, etc.). We believe that the last one - invoking a URL action (aka web-hook) - is particularly powerful since it lets you interact with and control any internet-enabled applications.

We will now see how easy it is to integrate IFTTT with 1btn with its URL invoking capability.

What’s needed for this configuration?

As this is IFTTT integration, you definitely need to have an IFTTT user account. Apart from that you’ll also need a 1btn and your smartphone with IFTTT app installed in it. This way we can activate some of the phone functionalities using IFTTT app, triggered by 1btn remotely.

In order to create a meaningful recipe, I have chosen timesheet recording as a task which can be done with 1btn and IFTTT together. With this integration, our 1btn can record timestamp each time it is pressed in a excel sheet on Google drive. We can then later crunch numbers in this excel sheet to calculate time spent on a task.

This integration is done in two stages; first part of it is to create a recording recipe on IFTTT and second part will be to create a hardware trigger for invoking that recipe using 1btn.

Part 1: Create a new recipe on IFTTT

The video shows how to create a timestamp logging recipe using IFTTT quickly and easily.

https://youtu.be/H0qe8yxNmFw

Part 2: Note down maker channel credentials

In order to invoke maker channel triggers, we need to have api_key with us. Part 2 of the video shows where and how to get this api_key. Make sure that you copy and store the entire link at the end of this step for 1btn configuration.

https://youtu.be/__Uo1v9UFuE

Part 3: Configure 1btn to trigger the IFTTT recipe

Once we have api_key from IFTTT channel our 1btn is ready to be configured for desired function. Part 3 of the video shows how to configure 1btn and invoke IFTTT maker channel URL when it is pressed.

https://youtu.be/Rz10mBNg4es

Time to test

If you have followed all the steps as per above three videos, your 1btn would by now be ready to record timestamps when pressed. Give it a try and enjoy the hardware shortcut for quick and easy data recording.

IFTTT presents umpteen numbers of triggers and actions. Even with using maker channel as a single trigger with 1btn, there are huge number of actions that could be triggered and this capability alone makes 1btn more powerful device. With community hacking – it’s powers would only increase further.

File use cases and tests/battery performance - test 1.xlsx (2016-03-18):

Sr. | Date | Time | Voltage
1 | 2015-12-25 | 21:47:50 | 4.1290
2 | 2015-12-25 | 22:11:41 | 4.1501
3 | 2015-12-25 | 23:40:56 | 4.1395
4 | 2015-12-25 | 23:45:33 | 4.1395
5 | 2015-12-26 | 11:31:30 | 4.1078
6 | 2015-12-26 | 11:54:33 | 4.0867
7 | 2015-12-26 | 11:56:18 | 4.0445
8 | 2015-12-26 | 11:56:40 | 4.0445
9 | 2015-12-26 | 11:57:59 | 4.0445
10 | 2015-12-26 | 11:59:45 | 4.0445
11 | 2015-12-26 | 13:13:20 | 4.0234
12 | 2015-12-26 | 15:33:36 | 4.0339
13 | 2015-12-26 | 16:32:07 | 4.0234
14 | 2015-12-26 | 17:51:05 | 4.0234
15 | 2015-12-26 | 17:51:40 | 4.0234
16 | 2015-12-26 | 17:53:41 | 4.0234
17 | 2015-12-26 | 17:54:12 | 4.0128
18 | 2015-12-26 | 20:04:29 | 4.0234
19 | 2015-12-26 | 20:10:17 | 4.0128
20 | 2015-12-26 | 20:19:35 | 4.0234
21 | 2015-12-26 | 20:19:52 | 4.0128
22 | 2015-12-26 | 20:27:35 | 4.0128
23 | 2015-12-26 | 20:29:29 | 4.0128
24 | 2015-12-26 | 21:05:17 | 4.0128
25 | 2015-12-26 | 21:50:04 | 4.0128
26 | 2015-12-26 | 23:41:52 | 4.0128
27 | 2015-12-27 | 3:48:21 | 4.0022
28 | 2015-12-27 | 12:09:30 | 3.9389
29 | 2015-12-27 | 12:12:38 | 3.9283
30 | 2015-12-27 | 13:00:29 | 3.9283
31 | 2015-12-27 | 13:00:44 | 3.9283
32 | 2015-12-27 | 13:00:55 | 3.9178
33 | 2015-12-27 | 13:01:42 | 3.9283
34 | 2015-12-27 | 13:22:12 | 3.9283
35 | 2015-12-27 | 13:31:08 | 3.9283
36 | 2015-12-27 | 13:31:32 | 3.9283
37 | 2015-12-27 | 14:01:37 | 3.8966
38 | 2015-12-27 | 14:01:37 | 3.9283
39 | 2015-12-27 | 14:04:16 | 3.9072
40 | 2015-12-27 | 14:04:41 | 3.9072
41 | 2015-12-27 | 15:10:09 | 3.9178
42 | 2015-12-27 | 15:34:08 | 3.9072
43 | 2015-12-27 | 15:40:35 | 3.9072
44 | 2015-12-27 | 15:42:13 | 3.9072
45 | 2015-12-27 | 15:42:38 | 3.9072
46 | 2015-12-27 | 15:43:08 | 3.9072
47 | 2015-12-27 | 15:43:26 | 3.8966
48 | 2015-12-27 | 15:43:44 | 3.8966
49 | 2015-12-27 | 15:43:59 | 3.8966
50 | 2015-12-27 | 18:54:45 | 3.8966
51 | 2015-12-27 | 18:57:26 | 3.8861
52 | 2015-12-27 | 21:58:26 | 3.8966
53 | 2015-12-27 | 22:05:52 | 3.8966
54 | 2015-12-27 | 22:29:56 | 3.8966
55 | 2015-12-27 | 22:37:01 | 3.8966
56 | 2015-12-28 | 1:37:01 | 3.8861
57 | 2015-12-28 | 10:26:00 | 3.8333
58 | 2015-12-28 | 10:27:24 | 3.8227
59 | 2015-12-28 | 10:28:32 | 3.8227
60 | 2015-12-28 | 10:40:43 | 3.8333
61 | 2015-12-28 | 10:41:48 | 3.8227
62 | 2015-12-28 | 15:45:38 | 3.8333
63 | 2015-12-28 | 16:05:21 | 3.8227
64 | 2015-12-28 | 16:23:23 | 3.8227
65 | 2015-12-28 | 18:14:44 | 3.7066
66 | 2015-12-28 | 18:15:02 | 3.7066
67 | 2015-12-28 | 18:15:17 | 3.7066
68 | 2015-12-28 | 19:12:15 | 3.7171
69 | 2015-12-28 | 21:36:55 | 3.7171
70 | 2015-12-28 | 21:37:48 | 3.7066
71 | 2015-12-28 | 21:38:13 | 3.7066
72 | 2015-12-28 | 21:51:30 | 3.7171
73 | 2015-12-28 | 21:52:03 | 3.7171
74 | 2015-12-28 | 21:54:41 | 3.7066
75 | 2015-12-28 | 22:48:57 | 3.7171
76 | 2015-12-28 | 23:17:50 | 3.7066
77 | 2015-12-29 | 0:25:00 | 3.7171
78 | 2015-12-29 | 9:02:20 | 3.7066
79 | 2015-12-29 | 9:23:30 | 3.7066
80 | 2015-12-29 | 9:34:29 | 3.7066
81 | 2015-12-29 | 15:02:55 | 3.8861
82 | 2015-12-29 | 15:04:46 | 3.9283
83 | 2015-12-29 | 15:46:42 | 3.7277
84 | 2015-12-29 | 15:47:23 | 3.9178
85 | 2015-12-29 | 15:47:39 | 3.9283
86 | 2015-12-29 | 15:47:54 | 3.9389
87 | 2015-12-29 | 15:57:01 | 3.9283
88 | 2015-12-29 | 15:59:54 | 3.7488
89 | 2015-12-29 | 16:00:18 | 3.7382
90 | 2015-12-29 | 16:01:37 | 3.7382
91 | 2015-12-29 | 16:02:44 | 3.7382
92 | 2015-12-29 | 16:04:19 | 3.7382
93 | 2015-12-29 | 16:04:47 | 3.7382
94 | 2015-12-29 | 16:05:06 | 3.7382
95 | 2015-12-29 | 16:05:35 | 3.7277
96 | 2015-12-29 | 16:06:03 | 3.7382
97 | 2015-12-29 | 16:06:23 | 3.7277
98 | 2015-12-29 | 16:06:43 | 3.7277
99 | 2015-12-29 | 16:07:10 | 3.7277
100 | 2015-12-29 | 16:07:24 | 3.7277
101 | 2015-12-29 | 16:07:24 | 3.7277
102 | 2015-12-29 | 16:07:37 | 3.7171
103 | 2015-12-29 | 17:10:51 | 3.7382
104 | 2015-12-29 | 18:05:09 | 3.7277
105 | 2015-12-29 | 18:05:42 | 3.7277
106 | 2015-12-29 | 18:14:57 | 3.7382
107 | 2015-12-29 | 18:15:43 | 3.7277
108 | 2015-12-29 | 18:17:00 | 3.7171
109 | 2015-12-29 | 18:17:06 | 3.7171
110 | 2015-12-29 | 18:19:52 | 3.7277
111 | 2015-12-29 | 18:20:32 | 3.7277
112 | 2015-12-29 | 18:20:45 | 3.7171
113 | 2015-12-29 | 18:23:37 | 3.7277
114 | 2015-12-29 | 18:31:18 | 3.7277
115 | 2015-12-29 | 19:02:45 | 3.7171
116 | 2015-12-29 | 19:26:42 | 3.7171
117 | 2015-12-29 | 19:28:26 | 3.7277
118 | 2015-12-29 | 19:28:47 | 3.7171
119 | 2015-12-29 | 19:29:00 | 3.7171
120 | 2015-12-29 | 19:29:12 | 3.7171
121 | 2015-12-29 | 19:29:34 | 3.7171
122 | 2015-12-29 | 19:29:50 | 3.7171
123 | 2015-12-29 | 19:31:46 | 3.7171
124 | 2015-12-29 | 19:32:04 | 3.7171
125 | 2015-12-29 | 19:44:02 | 3.7171
126 | 2015-12-29 | 19:53:37 | 3.7171
127 | 2015-12-29 | 19:54:06 | 3.7171
128 | 2015-12-29 | 19:54:49 | 3.7066
129 | 2015-12-29 | 19:55:00 | 3.7066
130 | 2015-12-29 | 19:55:38 | 3.7066
131 | 2015-12-29 | 22:28:05 | 3.7171
132 | 2015-12-29 | 22:29:12 | 3.7066
133 | 2015-12-29 | 22:29:40 | 3.7171
134 | 2015-12-29 | 22:30:37 | 3.7171
135 | 2015-12-29 | 22:31:50 | 3.7171
136 | 2015-12-29 | 22:32:23 | 3.7066
137 | 2015-12-29 | 22:34:50 | 3.7171
138 | 2015-12-29 | 22:36:13 | 3.7171
139 | 2015-12-29 | 22:38:26 | 3.7066
140 | 2015-12-29 | 22:38:41 | 3.7066
141 | 2015-12-29 | 22:41:53 | 3.7066
142 | 2015-12-29 | 22:43:16 | 3.7066
143 | 2015-12-29 | 22:44:53 | 3.7066
144 | 2015-12-29 | 22:59:53 | 3.7066
145 | 2015-12-29 | 23:03:24 | 3.7066
146 | 2015-12-29 | 23:09:17 | 3.6960
147 | 2015-12-29 | 23:10:38 | 3.7066
148 | 2015-12-29 | 23:14:00 | 3.6960
149 | 2015-12-29 | 23:15:09 | 3.6960
150 | 2015-12-29 | 23:18:14 | 3.6960
151 | 2015-12-29 | 23:20:10 | 3.6960
152 | 2015-12-29 | 23:42:43 | 3.7066
153 | 2015-12-30 | 1:44:17 | 3.6960
154 | 2015-12-30 | 1:44:38 | 3.6960
155 | 2015-12-30 | 1:44:53 | 3.6960
156 | 2015-12-30 | 1:45:25 | 3.6960
157 | 2015-12-30 | 3:58:42 | 3.6960
158 | 2015-12-30 | 4:21:18 | 3.7066
159 | 2015-12-30 | 4:36:46 | 3.6749
160 | 2015-12-30 | 4:37:28 | 3.6749
161 | 2015-12-30 | 4:38:10 | 3.6749
162 | 2015-12-30 | 4:38:24 | 3.6749
163 | 2015-12-30 | 4:38:36 | 3.6749
164 | 2015-12-30 | 9:13:14 | 3.6854
165 | 2015-12-30 | 11:40:55 | 3.6749
166 | 2015-12-30 | 11:41:09 | 3.6749
167 | 2015-12-30 | 12:08:04 | 3.6749
168 | 2015-12-30 | 12:27:26 | 3.6749
169 | 2015-12-30 | 13:40:12 | 3.6749
170 | 2015-12-30 | 13:40:28 | 3.6749
171 | 2015-12-30 | 13:40:44 | 3.6749
172 | 2015-12-30 | 13:40:54 | 3.6749
173 | 2015-12-30 | 13:41:13 | 3.6749
174 | 2015-12-30 | 13:41:28 | 3.6643
175 | 2015-12-30 | 13:41:49 | 3.6643
176 | 2015-12-30 | 13:42:00 | 3.6643
177 | 2015-12-30 | 13:42:11 | 3.6643
178 | 2015-12-30 | 13:54:23 | 3.6643
179 | 2015-12-30 | 13:55:25 | 3.6643
180 | 2015-12-30 | 13:57:32 | 3.6643
181 | 2015-12-30 | 14:18:34 | 3.6643
182 | 2015-12-30 | 15:41:18 | 3.6749
183 | 2015-12-30 | 18:50:10 | 3.6643
184 | 2015-12-30 | 19:22:14 | 3.6643
185 | 2015-12-30 | 19:26:12 | 3.6643
186 | 2015-12-30 | 19:49:01 | 3.6643
187 | 2015-12-30 | 19:56:05 | 3.6643
188 | 2015-12-30 | 21:36:30 | 3.6643
189 | 2015-12-30 | 21:36:45 | 3.6538
190 | 2015-12-30 | 21:37:15 | 3.6643
191 | 2015-12-30 | 21:37:35 | 3.6538
192 | 2015-12-30 | 21:38:04 | 3.6538
193 | 2015-12-30 | 21:38:18 | 3.6538
194 | 2015-12-30 | 21:38:38 | 3.6538
195 | 2015-12-30 | 21:39:02 | 3.6538
196 | 2015-12-30 | 21:39:19 | 3.6538
197 | 2015-12-30 | 21:39:37 | 3.6538
198 | 2015-12-30 | 21:39:54 | 3.6538
199 | 2015-12-30 | 22:37:56 | 3.6643
200 | 2015-12-30 | 22:38:10 | 3.6538
201 | 2015-12-30 | 22:38:20 | 3.6538
202 | 2015-12-30 | 22:38:34 | 3.6538
203 | 2015-12-30 | 22:38:53 | 3.6538
204 | 2015-12-30 | 22:39:08 | 3.6538
205 | 2015-12-30 | 22:39:29 | 3.6538
206 | 2015-12-30 | 22:39:43 | 3.6538
207 | 2015-12-30 | 22:40:02 | 3.6432
208 | 2015-12-30 | 22:40:35 | 3.6538
209 | 2015-12-30 | 22:40:50 | 3.6538
210 | 2015-12-30 | 22:41:14 | 3.6538
211 | 2015-12-30 | 22:41:48 | 3.6432
212 | 2015-12-31 | 0:08:40 | 3.6538
213 | 2015-12-31 | 0:30:35 | 3.6538
214 | 2015-12-31 | 1:13:59 | 3.6538
215 | 2015-12-31 | 2:57:18 | 3.6538
216 | 2015-12-31 | 11:03:59 | 3.6326
217 | 2015-12-31 | 11:04:12 | 3.6326
218 | 2015-12-31 | 11:16:08 | 3.6326
219 | 2015-12-31 | 11:43:23 | 3.6326
220 | 2015-12-31 | 11:56:40 | 3.6326
221 | 2015-12-31 | 11:56:57 | 3.6221
222 | 2015-12-31 | 11:58:05 | 3.6221
223 | 2015-12-31 | 13:58:51 | 3.6115
224 | 2015-12-31 | 19:25:53 | 3.4214
225 | 2015-12-31 | 19:26:28 | 3.4109
226 | 2015-12-31 | 19:27:30 | 3.4003
227 | 2015-12-31 | 22:22:28 | 3.1997
228 | 2015-12-31 | 23:00:27 | 3.1891
229 | 2015-12-31 | 23:21:36 | 2.9779
230 | 2015-12-31 | 23:21:53 | 2.9146
231 | 2015-12-31 | 23:22:12 | 2.8301
232 | 2015-12-31 | 23:48:35 | 2.9040
233 | 2016-01-01 | 4:30:54 | 2.4288

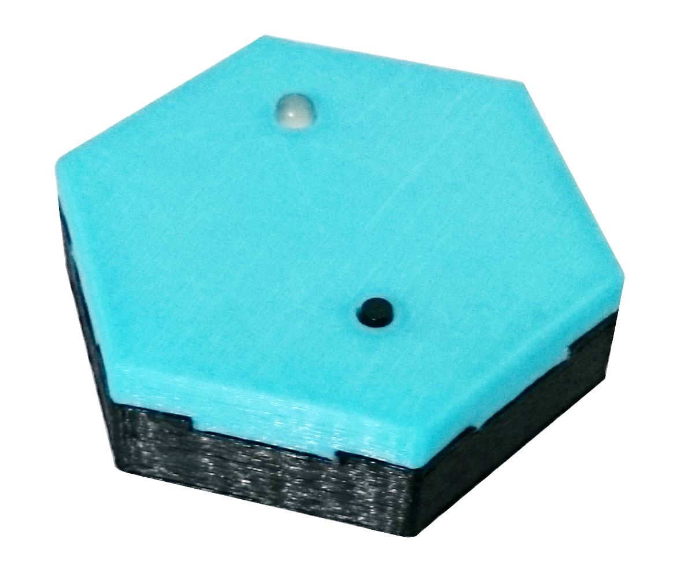
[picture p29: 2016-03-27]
use cases and tests/using_reed_switch_with_1btn/0_button_used_for_hack.jpg

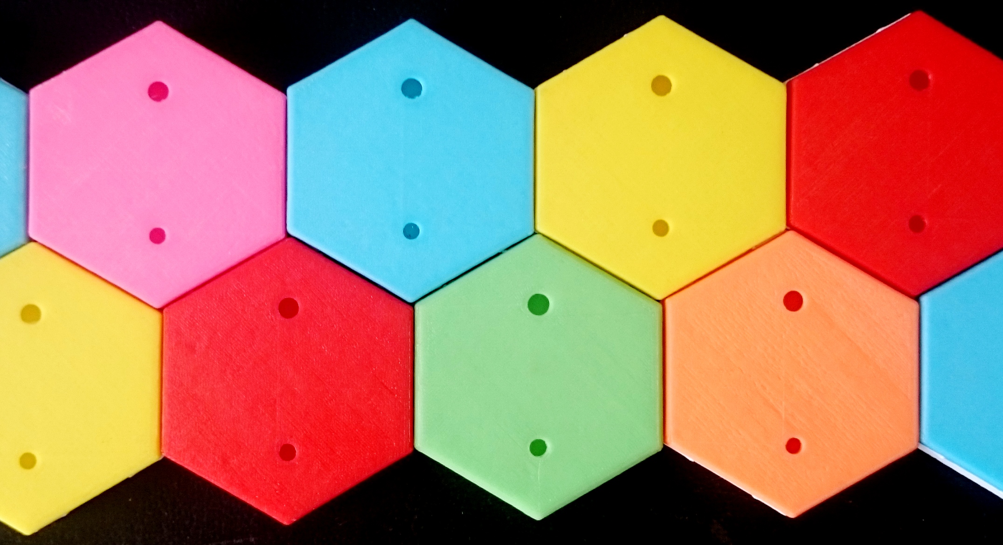
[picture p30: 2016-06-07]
use cases and tests/production_update_06_june_16/1btn enclosures.jpg

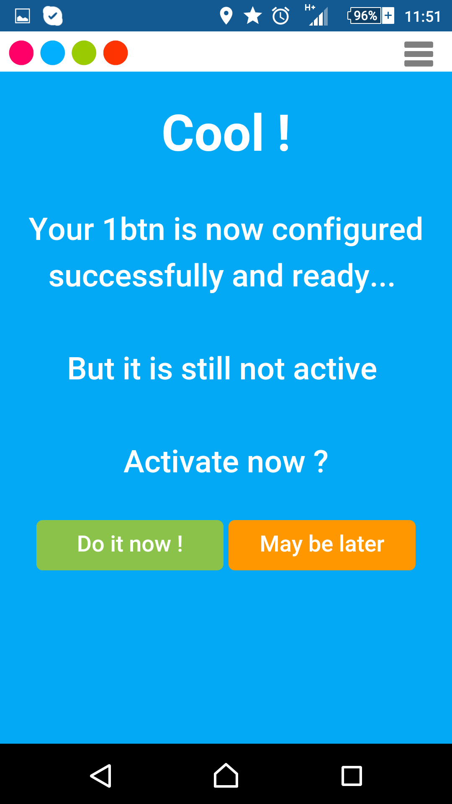
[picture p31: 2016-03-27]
use cases and tests/using_reed_switch_with_1btn/s6_activate_button.png

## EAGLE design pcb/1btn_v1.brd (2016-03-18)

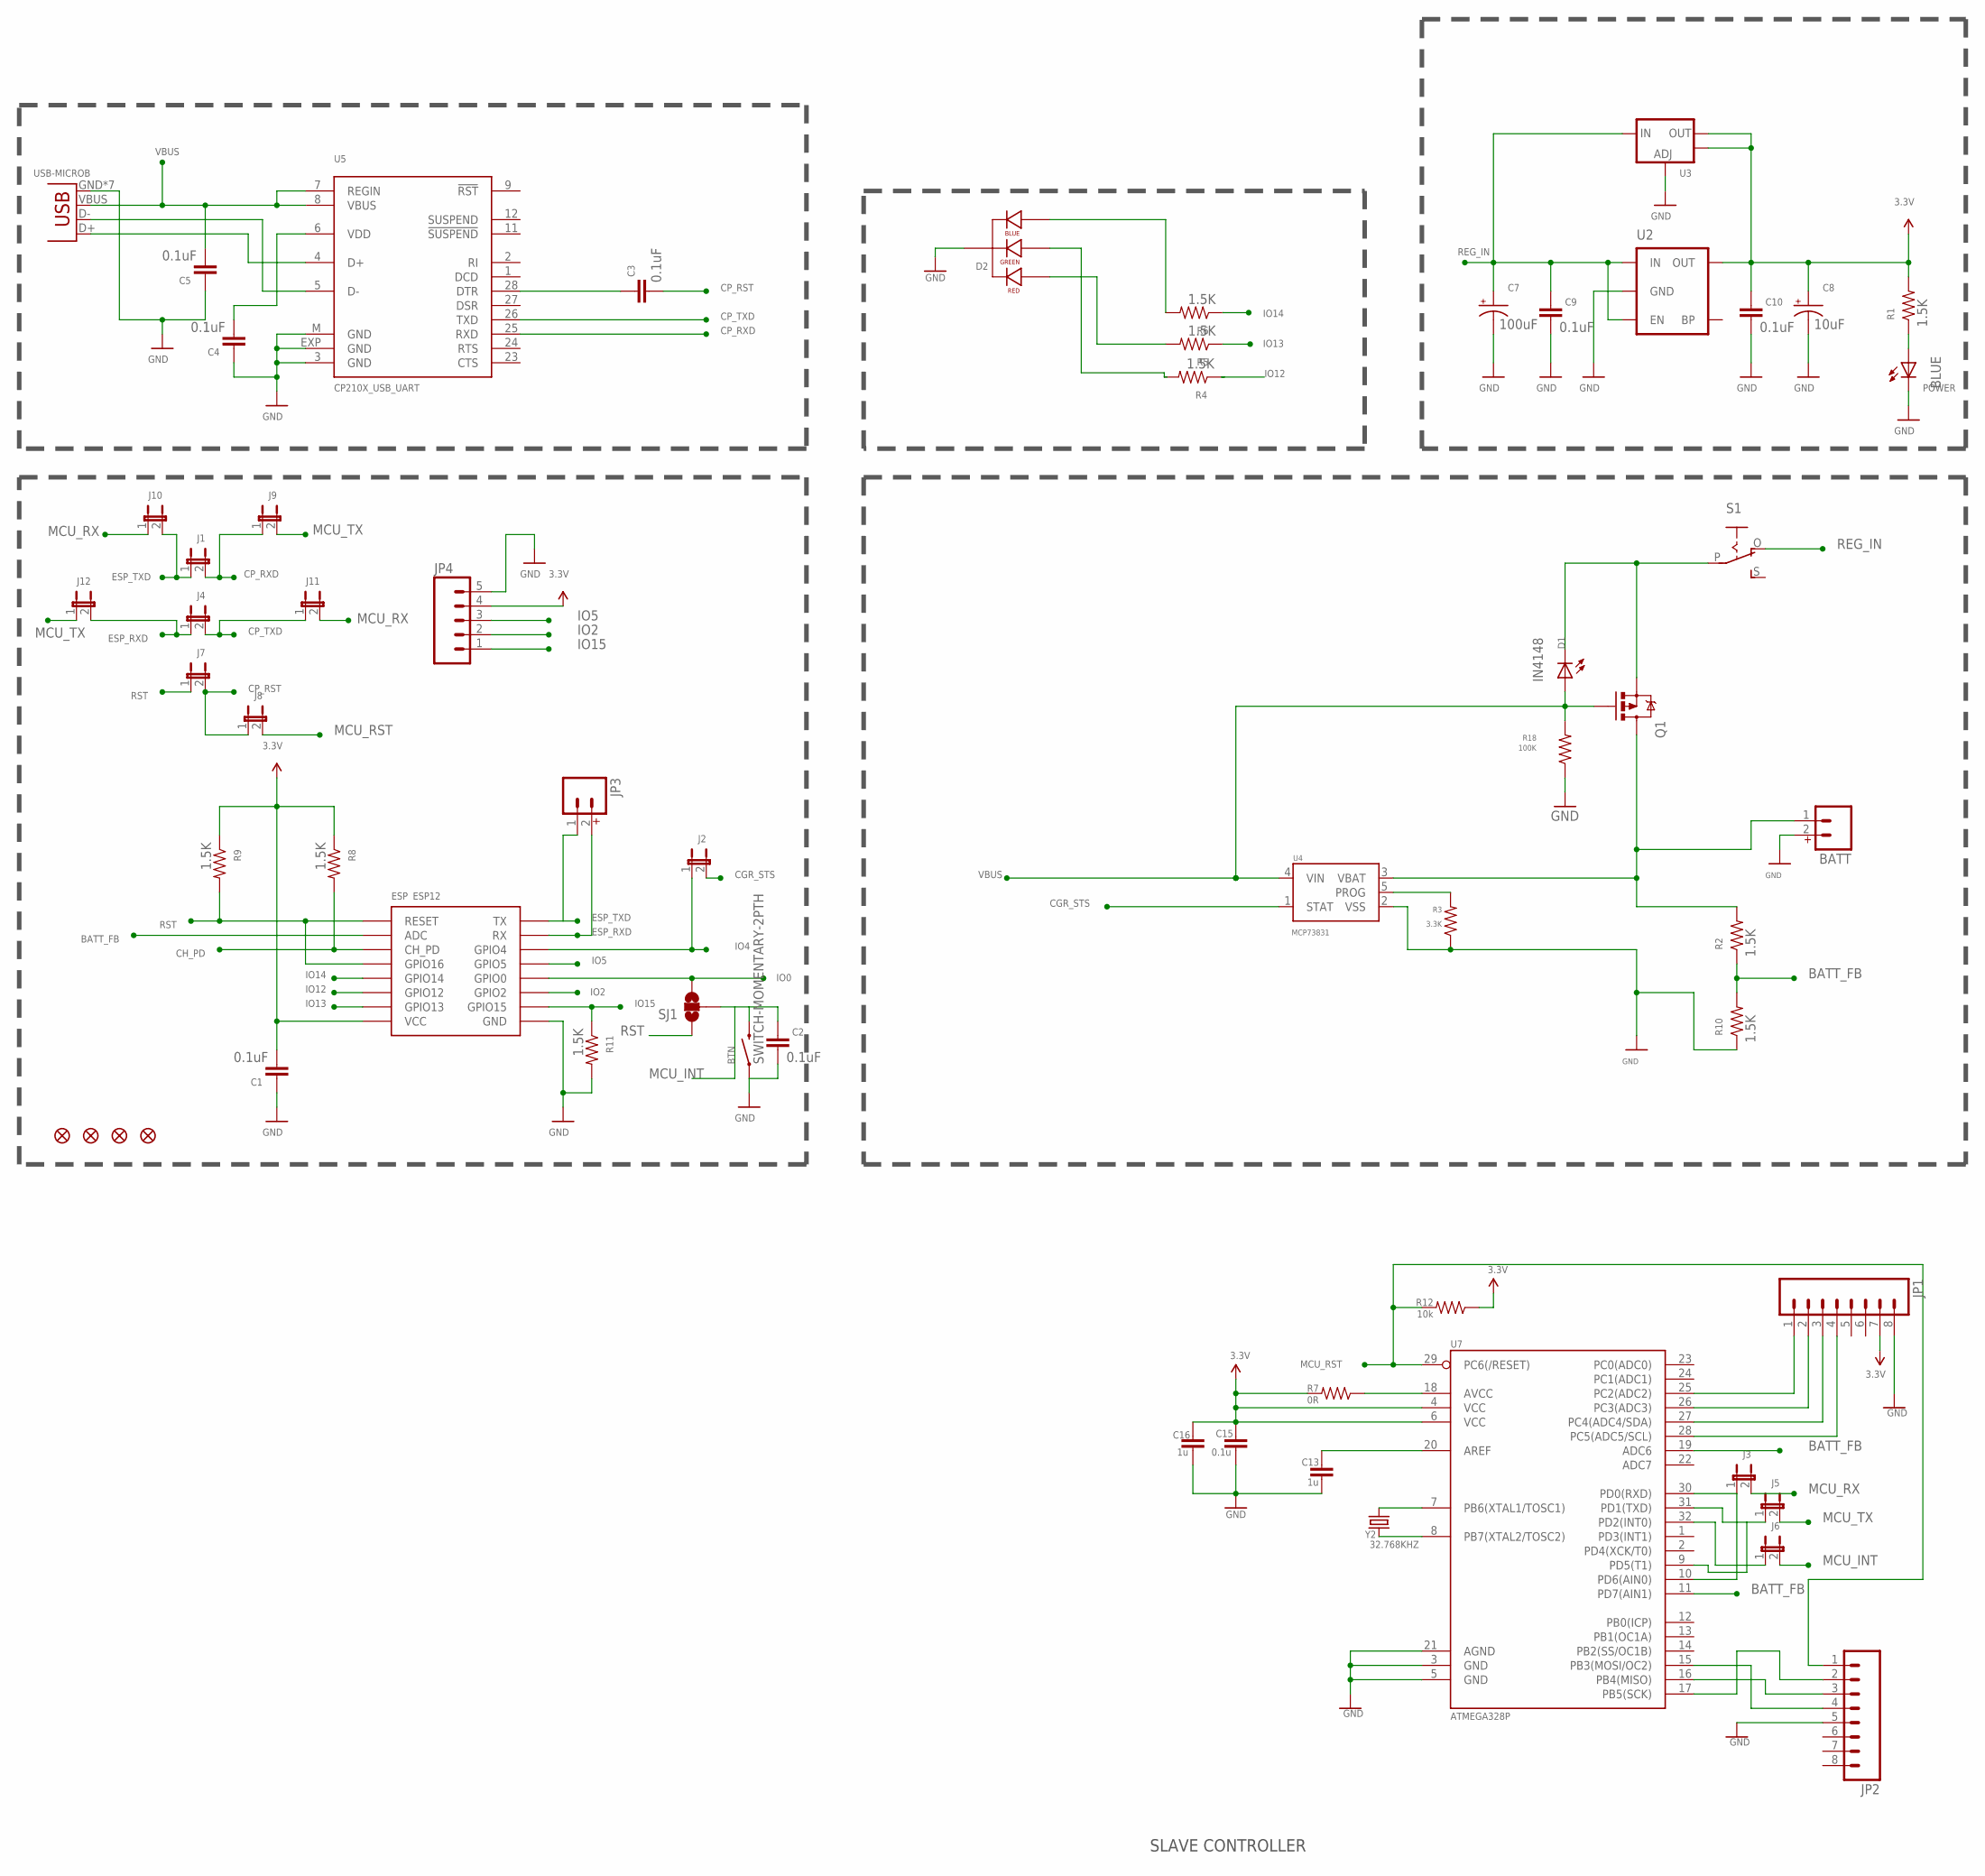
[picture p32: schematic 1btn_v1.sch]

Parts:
BATT: M02JST-PTH-2; JST-2-PTH
BTN: SWITCH-MOMENTARY-2PTH; TACTILE-PTH
C1, C2, C3, C4, C5, C9, C10: 0.1uF; 0805
C7: 100uF; EIA3216-KIT
C8: 10uF; EIA3216-KIT
C13, C16: 1u; 0805
C15: 0.1u; 0805
D1: IN4148; LED-1206
D2: LED-RGB-CC-THRUCLEAR; LED-RGB-THRU
ESP: ESP12
FID1, FID2, FID3, FID4: FIDUCIAL1X2; FIDUCIAL-1X2
J1, J2, J3, J4, J5, J6, J7, J8, J9, J10, J11, J12: JUMPER-2SMD-NC; SJ_2S
JP1, JP2: M08NO_SILK; 1X08_PIN1_NO_SILK
JP3: M02PTH; 1X02
JP4: M05PTH; 1X05
POWER: BLUE; LED-0805
Q1: MOSFET-PCHANNELSMD; SOT23-3
R1, R2, R4, R5, R6, R8, R9, R10, R11: 1.5K; 0805
R3: 3.3K; 0805
R7: 0R; 0805
R12: 10k; 0805
R18: 100K; 0805
S1: EG1218S; EG1218
SJ1: SOLDERJUMPER_2WAYS; SJ_3
U2: MIC52053.3V; SOT23-5
U3: V_REG_LM1117SOT223; SOT223
U4: MCP73831; SOT23-5
U5: CP210X_USB_UART; MLP28
U7: ATMEGA328P; TQFP32-08
USB: USB-MICROB
Y2: 32.768KHZ; TC26HEZ

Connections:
3.3V: C1.2, C8.A (+), C10.1, C15.1, C16.1, ESP.VCC, JP1.7, JP4.4, R1.2, R7.2, R8.1, R9.1, R12.1, U2.5 (OUT), U3.2 (OUT), U3.4 (OUT), U7.4 (VCC), U7.6 (VCC)
BA: D2.3 (GREEN_CATHODE), R4.2
BATT+: BATT.1, Q1.3 (D), R2.2, U4.3 (VBAT)
BATT_FB: ESP.ADC, R2.1, R10.2, U7.11 (PD7(AIN1)), U7.19 (ADC6)
CGR_STS: J2.2, U4.1 (STAT)
CH_PD: ESP.CH_PD, R8.2
CP_RST: C3.2, J7.2, J8.1
CP_RXD: J1.2, J9.1, U5.25 (RXD)
CP_TXD: J4.2, J11.1, U5.26 (TXD)
ESP_RXD: ESP.RX, J4.1, J12.2, JP3.2
ESP_TXD: ESP.TX, J1.1, J10.2, JP3.1
GND: BATT.2, BTN.1, C1.1, C2.2, C4.1, C5.1, C7.C (-), C8.C (-), C9.2, C10.2, C13.2, C15.2, C16.2, D2.2 (CATHODE), ESP.GND, JP1.8, JP2.5, JP4.5, POWER.2 (C), R3.1, R10.1, R11.2, R18.1, U2.2 (GND), U3.1 (ADJ), U4.2 (VSS), U5.3 (GND), U5.EXP (GND), U5.M (GND), U7.3 (GND), U7.5 (GND), U7.21 (AGND), USB.GND, USB.MT1 (GND), USB.MT2 (GND), USB.MT3 (GND), USB.MT4 (GND), USB.P$1 (GND), USB.P$2 (GND)
IO0: ESP.GPIO0, SJ1.3
IO2: ESP.GPIO2, JP4.2
IO4: ESP.GPIO4, J2.1
IO5: ESP.GPIO5, JP4.3
IO12: ESP.GPIO12, R4.1
IO13: ESP.GPIO13, R5.1
IO14: ESP.GPIO14, R6.1
IO15: ESP.GPIO15, JP4.1, R11.1
MCU_INT: BTN.3 (2), C2.1, J6.2, SJ1.2
MCU_RST: J8.2, JP2.1, R12.2, U7.29 (PC6(/RESET))
MCU_RX: J3.2, J10.1, J11.2
MCU_TX: J5.2, J9.2, J12.1
unnamed: D2.1 (RED_CATHODE), R5.2
unnamed: D2.4 (BLUE_CATHODE), R6.2
unnamed: D1.C, Q1.2 (S), S1.P
unnamed: U5.5 (D-), USB.D-
unnamed: C3.1, U5.28 (DTR)
unnamed: POWER.1 (A), R1.1
unnamed: U5.4 (D+), USB.D+
unnamed: JP1.1, U7.25 (PC2(ADC2))
unnamed: JP1.2, U7.26 (PC3(ADC3))
unnamed: JP1.3, U7.27 (PC4(ADC4/SDA))
unnamed: JP1.4, U7.28 (PC5(ADC5/SCL))
unnamed: R3.2, U4.5 (PROG)
unnamed: JP2.4, U7.15 (PB3(MOSI/OC2))
unnamed: JP2.3, U7.16 (PB4(MISO))
unnamed: JP2.2, U7.17 (PB5(SCK))
unnamed: J3.1, U7.10 (PD6(AIN0)), U7.30 (PD0(RXD))
unnamed: J6.1, U7.32 (PD2(INT0))
unnamed: J5.1, U7.9 (PD5(T1)), U7.31 (PD1(TXD))
unnamed: U7.7 (PB6(XTAL1/TOSC1)), Y2.2
unnamed: U7.8 (PB7(XTAL2/TOSC2)), Y2.1
unnamed: C13.1, U7.20 (AREF)
unnamed: R7.1, U7.18 (AVCC)
REG_IN: C7.A (+), C9.1, S1.O, U2.1 (IN), U2.3 (EN), U3.3 (IN)
RST: ESP.GPIO16, ESP.RESET, J7.1, R9.2, SJ1.1
VBUS: C5.2, D1.A, Q1.1 (G), R18.2, U4.4 (VIN), U5.7 (REGIN), U5.8 (VBUS), USB.VBUS
VDD: C4.2, U5.6 (VDD)

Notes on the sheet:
SLAVE CONTROLLER

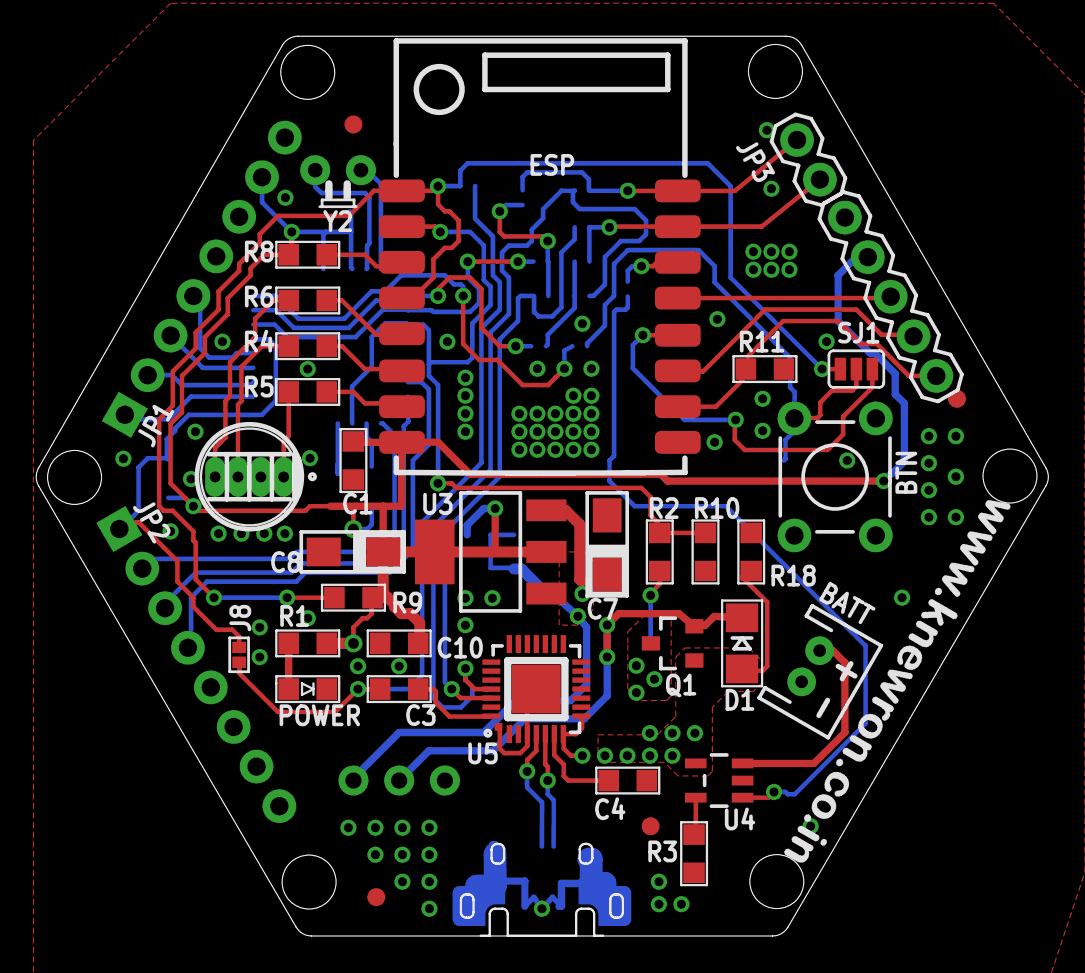
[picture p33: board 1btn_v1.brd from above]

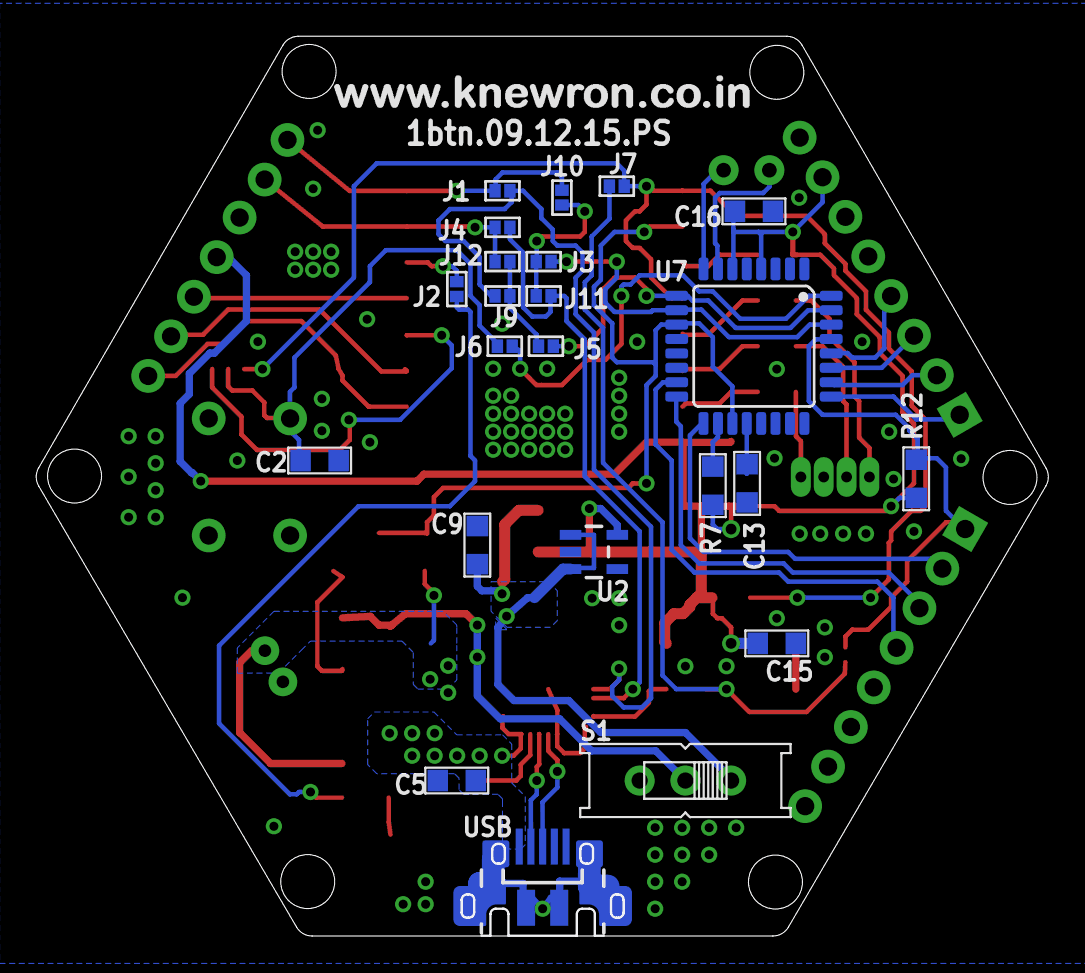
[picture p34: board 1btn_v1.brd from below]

Board: 2 copper layers, 56.2 x 50.0 mm, 63 parts (24 on the bottom side), 50 nets.

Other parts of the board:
U$2, U$3: WEBLINK-2

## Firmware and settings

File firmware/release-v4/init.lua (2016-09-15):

-- setup uart at 9600bps by default with echo
uart.setup(0, 9600, 8, uart.PARITY_NONE, uart.STOPBITS_1, 1);

rawcode, reason = node.bootreason();
-- bootreason() returns a stored value, which normally would be (2,5).
-- To get to this mode below do a slow double-click of the reset button.
if rawcode == 2 and reason == 6 then
	print("\nWaiting 5 seconds before sleep...");
	tmr.alarm(0, 5000, tmr.ALARM_SINGLE, function()
		node.dsleep(0);
	end);
else
	local fName = "setup.lc";

	if file.open(fName) ~= nil then
		file.close(fName);
		dofile(fName);
	else
		print(fName.." does not exist !");
	end
end

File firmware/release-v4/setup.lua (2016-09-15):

-- gpio pin mapping
RED = 1;
GREEN = 2;
YELLOW = 3;
BLUE = 4;
MAGENTA = 5;
CYAN = 6
WHITE = 7;

redLED = 7;
greenLED = 6;
blueLED = 5;

node.setcpufreq(node.CPU160MHZ);

-- set LED pins as output
gpio.mode(redLED, gpio.OUTPUT);
gpio.mode(greenLED, gpio.OUTPUT);
gpio.mode(blueLED, gpio.OUTPUT);

function setLED(ledColor)
     if bit.isset(ledColor, 0) then
          gpio.write(redLED, gpio.HIGH);
     else
          gpio.write(redLED, gpio.LOW);
     end

     if bit.isset(ledColor, 1) then
          gpio.write(greenLED, gpio.HIGH);
     else
          gpio.write(greenLED, gpio.LOW);
     end

     if bit.isset(ledColor, 2) then
          gpio.write(blueLED, gpio.HIGH);
     else
          gpio.write(blueLED, gpio.LOW);
     end
end

function blinkLED(ledColor, blinkTimes)
     for j = 1, blinkTimes do
          setLED(ledColor);
          tmr.delay(250000);
          setLED(0);
          tmr.delay(250000);
     end
end

-- configure wifi
wifi.setmode(wifi.STATIONAP);

setLED(0);

dofile('btn.lc');

-- clean up
collectgarbage("collect");

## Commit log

2016-03-18 Added mechanical designs
    [bottomcase5.1_07032016.stl, top coverv5.1_07032016.dwg]
2016-03-18 PCB files added
    [1btn_full_bom_08mar16.xlsx, 1btn_v1.brd, 1btn_v1.sch]
2016-03-18 Battery test results added
    [battery performance - test 1.xlsx]
2016-03-18 Battery test results updated
    [battery performance - test 1.xlsx]
2016-03-27 use case 1 added
2016-04-04 IFTTT timelogger use case added
2016-04-23 BOM and use case files updated
    [1btn_full_bom_08mar16.xlsx]
2016-05-11 schematic file added in image format
2016-08-15 firmware v3 with configuration bug resolved
    [init.lua, setup.lua]

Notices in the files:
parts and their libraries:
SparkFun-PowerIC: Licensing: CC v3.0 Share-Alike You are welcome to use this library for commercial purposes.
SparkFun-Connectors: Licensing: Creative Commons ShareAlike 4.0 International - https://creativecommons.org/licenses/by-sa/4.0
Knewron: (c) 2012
